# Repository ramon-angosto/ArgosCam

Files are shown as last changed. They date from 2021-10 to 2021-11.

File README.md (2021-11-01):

# ArgosCam
This project is the result of my bachelor degree final projects, for my studies in mechatronical engineering, a copy of the complete documentation of the project can be found in the documentation folder. <!-- link a carpeta -->

## Introduction

The idea of this project is the development and prototyping of a system to increase the visibility of drivers at street intersections to reduce the number of accidents that occur in these areas.

Reduced visibility increases the risk of collisions with vehicles approaching the perpendicular street to which the driver is going. Especially if the driver has to invade the road, he wants to incorporate, with his car to have visibility. This problem occurs mainly in rural areas where the streets are narrower and at the exits of the parking lots where many times the car has to cross the sidewalk to enter the street, creating a risk of running over a pedestrian.

The project develops a system to be called ARGOS CAM, referring to Greek mythology in Argos Panoptes.

ARGOS Cam consists of two main parts: one that is responsible for the collection of vehicle data (i.e. speed) and a second part that is responsible for capturing images. This second module - focused on image processing - is responsible for offering help to the driver, through image recognition, and is modulated by the first, which focuses more on aspects of vehicle electronics. The figure 1, reperesents the pipeline of the project.

<p align="center">
  pipeline
</p>

Figure 1: pipeline of the project

In Figure 2 you can see an image that represents the advantage of the system for the driver, if two cameras are placed at the front of the car.

<p align="center">
  distance_advantage
</p>

Figure 2: Distance between the driver and the front of the car

This method has some advantages in front of traditionals methods, like convex mirrors, because it's directly attached to the car and can be adjusted, also the device notifiy the user of vehicles and persons approching the car.

## Methodology
### Vehicle data collection
In order to collect the data from the car an OBD II reader will be used. This devices connects diretly to the OBD Port of the car. The speed is the only value collected from the car and will be used to turn on and off the screen, depending if the speed is below a threshold by default stablished to 2 km/h. This is done to avoid creating distractions to the driver. 

<p align="center">
  USB Obd reader
</p>

Figure 4: USB OBD II Reader

The one I have used is this [OBD Reader](https://www.amazon.es/dp/B08DG4CFH8/ref=cm_sw_em_r_mt_dp_6RFKPJA6RXC36EJ8QV0E).

### Image Capture
Any machine vision system has a first phase of image acquisition. For this task I have used two cameras **Raspberry piCameras V2** of 8 Megapixels. This are placed at the front of the car, in figure 5 you can see the point where they are placed.

<p align="center">
  camera
</p>

Figure 6: Examples of taken images

### Embedded system
The embedded system selected for this project is the [Jetson nano B01](https://www.nvidia.com/es-es/autonomous-machines/embedded-systems/jetson-nano/) from the company **Nvidia**. This board has the advantage of beeing able to acces the **CUDA** library of Nvidia and also has a **GPU**, this makes it perfect for computer vision aplications as it has a better performance than a **Raspberry Pi 4**. 

<p align="center">
  jetson nano
</p>

Figure 7: Nvidia Jetson Nano B01

The OS version I used for the project was Jetpack 4.5

The programming language used is python. A detailed explanation of the libraries used can be found in the READ_ME file inside the folder called [Code](https://github.com/ramon-angosto/ArgosCam/tree/main/code).

<p align="center">
  Jetson connections
</p>

Figure 8: Representation of component connections with the Jetson Nano. The materials used for the project are: two Raspberry Pi v2 cameras, used for image capture; a touch screen to view images and interact with the user interface; an OBD reader used for vehicle data collection; a portable battery of the Xiaomi brand, with power capacity of 5v 2.6A;for GPIO connections, four LEDs and a buzzer are used (with the necessary additional components, explained on the READ me file inside the folder called electronics) <!-- link a carpeta -->

### Background subtraction
Images acquired by front-facing cameras are processed through the Background Subtraction algorithm to isolate those objects that are moving in the scene. This is done to avoid detecting parked cars and mislabel static elements.

The algorithm used is **K-NN Background subtraction**, and can be found inside the **OpenCV library**

The selected algorithm is based on the Gaussian Mixture Model (GMM), and el K-nearest neighbor (K-NN). This is described in depth [here](https://www.sciencedirect.com/science/article/abs/pii/S0167865505003521). Generally speaking, a recursive method is presented to update the GMM parameters and update them for each pixel.

Model initialization is performed with the number of frames assigned to the NSamples variable. During this period, you define which objects belong to the background class and which objects of the moving object class by comparing the pixels in these frames. The model is then updated every N of frames, where N is the number of frames that have been defined in the History and parameter.

After the background sustraction is applied, the results goes throug a series of postprocessing steps (Backround sustraction image -> Blur -> Morphological transformations(Opening -> Closing -> Dilate) -> Contour selection).

<p align="center">
  Background sustraction 'algorithm' steps
</p>

Figure 9: Background sustraction "algorithm" steps

This allow to obtain the desired result. In this case a rectangular shaped masked arround the moving objects.

 Result examples:
 <p align="center">
  Background sustraction results
</p>

### Object detection
After the Background Subtraction, object detection is performed. Thanks to the previous step, static objects, such as parked cars, will not be recognized. This prevents the driver from being misreported, who must be alert to objects that may pose a hazard (for example, an approaching car or a pedestrian crossing the street).

To perform this task, the Mobilenet-SSD v2 network will be used pre-trained with the [COCO(Comon Object in Context)](https://cocodataset.org/#home) data set, being able to recognize up to 90 different objects and the background [35]. This network consists of two main components: MobileNet , a deep neural network with an efficient architecture designed to be used in devices with less computing capacity such as phones and embedded systems, and an SSD (Single Shot Multibox Detector) network, which allows the simultaneous detectionof multiple objects in an image.

The objects that are recognized, i.e., the permitted classes, are: vehicles (bicycles, buses, cars, motorcycles) and people. If an object is not in the classes mentioned above, it would not be detected.

When any object of the set objects is recognized, for the first time since the car stops at an intersection, a noise will sound to warn the driver. This will not sound again until some class is no longer detected while the vehicle is still stopped or once the car moves again and stops at a new intersection.

In addition to the audible warning, the device has light warnings to identify if what has been detected is a pedestrian or a vehicle and which side it is on. This will remain active as long as one of the allowed classes is detected. In the next section you can see in more detail how you will see the output that the driver will receive.

<p align="center">
  Detection representation
</p>

Figure 10: Detection representation.

## User interface and alerts
### GUI
In order to create an interface to allow the driver to interact with the device using the screen a UI has been created using PysimpleGUI. The user will be able to interact with the GUI while the car is moving at a speed of less than 2 km/h or is stopped, and will be able to decide if both cameras are used or only one. In addition to this, a button has been incorporated that allows you to disable the recognition of objects in case the driver only wants to have the cameras active and not the warnings. Below are the different screens that the user will see:

<p align="center">
  GUI screens
</p>

Figure 11: GUI screens. A) Charging screen B) Screen while the vehicle is in motion C) Screen with a single camera D) Screen with both cameras

### Luminous and sound warning
The luminous and sound warnings will activated when any of the relevant objects are recognized. There are four light signals, 2 on each side. In this way, the driver can quickly know on which side, the object has been detected. Light signals are divided into two categories: people and vehicles (cars, motorcycles, bicycles and trucks).

### 3D Design
To encapsulate the project, a housing has been designed for the screen, battery, recessed system, and electronic board, and a different one for each camera. This task was carried out using the CAD Fusion 360 program. In the folder called 3D, the following files are included: instruccions to build it and the stl. files.

<p align="center">
  ARGOS CAM
</p>

Figure 12:  ARGOS CAM system mounted on a car

## A video of the project can be found [here](https://youtu.be/hri5eU1GCwE)

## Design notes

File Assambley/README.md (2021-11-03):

# Assambley
## Materials to assamble this project
- Obd reader
- Power supply or power bank
- Jetson Nano B01 or higher version
- Sd card
- 3D printed parts
- Electronic circuit found in electronics folder
- 2 Raspberry pi cameras
- Touch Screen 
- HDMI cable
- Microusb to usb cable

## Electronics
Contains the electronics circuit and a list of components. **Go to [this folder](./Electronics/) first**

## 3d
Contains the files that have to be printed and the components to assamble the parts. **Also the instructions on how to assamble the casing.**

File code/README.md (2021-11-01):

# Necessary libraries: 
- [PySimpleGUI](https://pysimplegui.readthedocs.io/en/latest/)
- [Jetson.GPIO](https://github.com/NVIDIA/jetson-gpio)
- threading
- [obd](https://python-obd.readthedocs.io/en/latest/)
- [jetson.inference](https://github.com/dusty-nv/jetson-inference)
- [jetson.utils](https://github.com/dusty-nv/jetson-utils)
- queue

### Follow [this instruccions](https://www.pyimagesearch.com/2020/03/25/how-to-configure-your-nvidia-jetson-nano-for-computer-vision-and-deep-learning/) to intall this libraries ###
- Numpy
- OpenCv with CUDA support and contrib modules 

# Files explanation #
All the codes have comments to make them easier to understand

## synchronized_cameras_recognition_modes and video_algorithms ##
Contain the algorithms to control the cameras using threads. Also the functions to apply the background subtraction and object recognition while managing the GPIO pins.

## GPIO_ ##
This simple code can be used to test if the GPIO pins are set correctly without having to execute the complete code

## Simulation_ARGOS_CAM ##
As the name says is a simulator of how the code will perform when integrated on the car. This code dosen't require to use an OBD reader, the speed is emulated using an slider. The other parts of the code work as if they where integrated in the car.

## ARGOS_CAM ##
This code has to be executed when the board is connected to the obd reader, if not it's not going to work. It reads the values of the obd reader and with the obtained values regualte if the cameras capture images or not. The user can choose which camera is shown or if both are shown. 

## test ## 
 Contains two videos that can be tested in the **Simulation_ARGOS_CAM** algorithm.

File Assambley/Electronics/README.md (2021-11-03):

# Electronics
## Components
- Buzzer
- x4 LED
- x5 220 Ohm
- x4 Transistor P2N2222A
- x4 330 Ohms
- PCB board (70 x 48) mm
- Jumper wires

## Instructions
Solder the components following the [elecronic circuit](./electronic_circuit.jpg).
- If you want to print the case, solder all the components and the wires, except the LEDs and the buzzer, and go to the [3D folder](../3D/) for more instruccions. 
- If you don't want to print the casing you can solder all the components.

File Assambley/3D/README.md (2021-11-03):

**The base of the jetson nano case is made specifically to be used in a Mini Cooper R50, this part shoud be modifies to addapt it to other vehicles. Also the battery hole is though for a xiaomi 3 pro powerbank**

- GoPro attachment with sticker. (Used to attach cameras to the car)

# Case for the Sceen/board/pcb/powerbank
## Materials
- 3d Printer filament

### Screw (Units, type) 
- x3 (M4 x 10) (Used to attach the jetson nano case to the screen case)
- x8 (Wood screw flat M2 x 8) (Used to attach the covers to the screen case)
- x6 (M2 x 12) (Used to attach the Jetson Nanano and the pcb to the jetson nano case)
- x4 (M2 x 20) (Used to attach the screen)

### Nuts (Units, type) 
- x3 M4 
- x10 M2

### Washer
- x3 M4
- x18 M2

# Instructions
In firs place, print all the stl. files
- x6 spacers
- x2 Gopro clip
- x2 Camera case back
- **LED Cover *special instructions**
- Print all the other pieces, only one time.
- **pcb components soldered, except LEDS and BUZZER, only the correspondent cables**

## *LED Cover instructions
Preferably have a tranparent filament for the printer. This is a way to do a multimaterial print with one extruder. If you have a multimaterial printer this step will be easier.

In first place print the drawings file, using a black filament if you have some, once the print is done, don't remove it from the build plate.
Change the material, to the transparent one in case you have some, or to another color. 

With the other component (stl name: drawings), still on the build plate, start printing the cover for the LEDS (stl name: circles).

## Jeston Nano and pcb case
In first place, introduce the nuts (x6 M2), through the bottom holes of the base (stl name: Jetson_nano_base). Once this is done, the jetson nano and the pcb can be fixed to the base, using the appropiate screws x6 (M2 x 12). **Remember** to use an spacer (stl. file), between the base and the board, and also a washer between the boards and the screw.

In second place put the cover of the jetson nano case (stl name:jetson_nano_case_cover). **Before fixing it down** attach the camera cables to the jetson nano and pass it through the holes found on the top of the jetson nano case (stl name:jetson_nano_case_cover). 

Use a wood screw to hold in place the cover and the base.

## Screen case
In first place inrtoduce three M4 nuts in the appropiate hols in the interior part of the case (stl names: screen_case and screen_case1) . After this, lay the model flat on it's back, and using a tweezers introduce x4 M2 nuts, on the four holes, located at the corners of the design, and also introduce four washers in the holes located over the nuts. Also use two wood screws to hold both parts of the screen case, one hole is found under the 3 nut holes, and the other on the back part of the case.

Once this is done carefully introduce the screen and secure it using x4 (M2 x 20). **Remeber** to introduce the screen with the hdmi facing the inside. 

After the screen is fixed in place and the powerbank it's put inside the case the lid of the case (stl name: screen_case_side_cover), can be screwed down using 3 wood screws.

## Attach Jetson nano case to screen case
To join these two pieces, x3 (M4 x 10) have to be used. In the back side of the base (stl name: Jetson_nano_base), introduce three washers and using the m4 screws fix this piece to the screen case.

Then pass through the holes, at the top of the screen case, the cables for the LEDs and the buzzer, and solder the components. Use the back covers (stl name: L/R _side_cover_screen_case), to cover the cables of the screen case. Use wood screws.

Finally put the covers with the symbols for the LEDS.

# Case for the Cameras
## Materials
- 3d Printer filament
- x2 Gopro sticker attachment

### Screw (Units, type) 
- x3 (M4 x 10) (Used to attach the camera case to the gopro clip)
- x8 (M2 x 16) (Used to attach the front and the back part of the camera case)

### Nuts (Units, type) 
- x2 M4 
- x8 M2

### Washer
- x2 M4
- x8 M2

## Instructions

In firs place, print all the stl. files
- x2 Gopro clip
- x2 Camera case back
- x1 Camera case front right 
- x1 Camera case front left

### Gopro clip
Print two copies of this file, ensure it's correctly printed as it has to hold the cameras attached to the car.
Introduce a M4 washer through the bottom hole.

### Camera case
This instructions have to be followed for each camera. 
Introduce x4 M2 nuts through the holes of the back part of the case of the camera (stl name: Camera case back).
Introduce x4 M2 washer through the holes of the front part of the case of the camera (stl: Camera case front R/L )
Use the M2 screws to hold it all togheter, putting the camera in between the two parts of the case.

Introduce a M4 nut at the bottom of the front part of the case of the camera (stl: Camera case front R/L)

Using an M4 screw join the Gopro clip and the camera case

**The design is completly build. Now place it inside the car and TRY IT.**

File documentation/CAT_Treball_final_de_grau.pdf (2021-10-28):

# TREBALL FINAL DE CARRERA

### SISTEMA PER REDUIR RISC D’ACCIDENTS A CANTONADES (ARGOS[1] CAM)

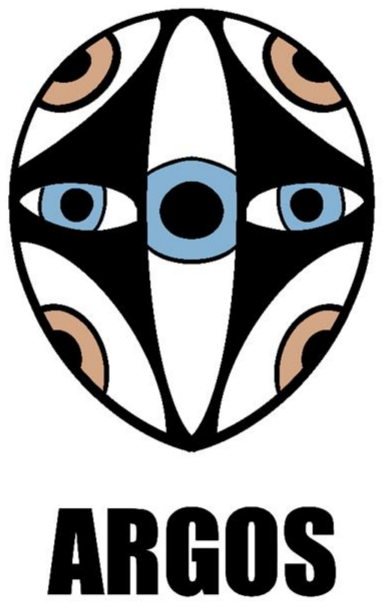
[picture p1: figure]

Nom: Ramon Angosto Artigues

Assignatura: Treball de final de grau

Grau en enginyeria mecatrònica.

Professor/a: Laura Dempere-Marco

27 octubre de 2021

Enginyeria mecatrònica

Treball de final de grau

Treball de final de grau

ÍNDEX DE CONTINGUT

Treball de final de grau

ÍNDEX D'IL·LUSTRACIONS

Il·lustració 8: Representació de les connexions dels components amb la Jetson Nano. Els materials usats per al projecte són: dues càmeres Raspberry Pi v2, usades per a la captura d’imatges; una pantalla tàctil per a la visualització d’imatges i interactuar amb la interfície d’usuari; un lector OBD usat per la recol·lecció de dades del vehicle; una bateria portàtil de la marca Xiaomi, amb capacitat per alimentar a 5v 2.6A; per a les connexions GPIO, s’usen

Il·lustració 10: A) Imatge Original B) NSamples amb valor 10 C) NSamples amb valor 3 .....26

Il·lustració 15: Etapes del Background Subtraction. a) Imatge original b) Blur c) Algoritme KNN

Il·lustració 16: Representació figurativa de capa depthwise separable (Font: Referència [37])

Il·lustració 18: Pantalles de la GUI. A) Pantalla de carrega B) Pantalla mentre el vehicle està

Treball de final de grau

Il·lustració 20: Peces de la carcassa de pantalla, bateria i plaques. A) Tapa carcassa placa
B) Base carcassa placa C ) i D) Tapes part posterior carcassa pantalla E) Carcassa pantalla
i bateria | 34
Il·lustració 21: Carcassa de la càmera dreta | 34

Il·lustració 22: Exemplificació de la GUI amb el cotxe parat, i amb el cotxe en moviment .35

Il·lustració 23: Visió de les càmeres des del punt de vista del conductor | 36

Il·lustració 24: Comparació de les mascares dels algoritmes de background Subtraction..37

Il·lustració 25: Exemples del Background Subtraction aplicat | 39
Il·lustració 26: Exemples dels avisos lluminosos en diferents situacions | 43
Il·lustració 27: Sistema Argos Cam muntat al cotxe | 44

ÍNDEX DE TAULES

Taula 1: Avaluació algoritmes de Backgroud Subtraction | 37
Taula 2: Comparació resultats algoritmes detecció d’objectes [35],[11],[22], [40] | 40

Taula 3: Velocitat de processament del reconeixement d'objectes en diferents situacions41

Taula 4: Numero de mostres per classe, i valors de TP, FP i FN | 42
Taula 5: Resultats avaluació reconeixement d'objectes | 42

Treball de final de grau

### 1. ABSTRACT

1.1 CATALÀ

En el següent Treball de Final de Grau, s’exposa el projecte dut a terme per al desenvolupament d’un dispositiu que té per objectiu augmentar la visibilitat dels vehicles a les cantonades per tal d’evitar accidents. Concretament al treball s’explicaran els mètodes que s’usen per a la identificació de possibles fonts de perill, la integració al vehicle del dispositiu i el mètode de notificació al conductor.

El projecte té dues línies metodològiques principals: 1) adquisició, processament d’imatges i reconeixement d’objectes, i 2) disseny del dispositiu electrònic. Aquestes dues línies de treball s’integren en un dispositiu funcional que un cop processades les imatges, juntament amb l’anàlisi de l’estat de moviment del vehicle, emet avisos sonors i lluminosos que indiquen la presència de vianants o vehicles que s’aproximen pels laterals.

Per dur a terme això, en primer lloc, s’han adquirit una sèrie de vídeos que han estat usats per a la realització de les proves, de forma prèvia a la integració al vehicle. Quant a la programació, aquesta s’ha dut a terme amb una Jeston Nano i el llenguatge Python junt amb una sèrie de llibreries open source, entre les quals destaca OpenCV. El disseny del dispositiu s’ha dut a terme amb el programa de disseny 3D Fusion360.

Així doncs, l’objectiu principal del projecte és augmentar la visibilitat del conductor quan es troba a una cantonada intentant girar. El dispositiu construït permet incrementar la visibilitat del conductor mitjançant l’ús de dues càmeres situades a la part del davant del cotxe i indicarà la presència d’objectes perillosos.

Els resultats obtinguts són prometedors. Per una banda, mostrar la imatge de la part frontal del cotxe ja suposa un gran avantatge de visibilitat. A més, als vídeos usats per realitzar les proves, en dies solejats o ennuvolats i les proves realitzades fora del cotxe, s’han obtingut resultats satisfactoris ja que s’avisava correctament al conductor quan un vehicle o vianant s’estava aproximant. En canvi, en condicions adverses, com pluja i boira, s’han observat alguns problemes de reconeixement dels vehicles i persones. També, a causa de la limitació de potencia al connectar la placa a una bateria portàtil per incorporar-la al cotxe aquesta no ha tingut el funcionament esperat i no ha donat els avisos correctament.

En definitiva, el projecte ha mostrat resultats que fan pensar que aquest dispositiu, amb una mica més de desenvolupament, podria ser incorporat com un sistema més d’assistència a la conducció.

Treball de final de grau

1.2 ANGLÈS

In the following Final Degree Project, the project carried out for the development of a device is exposed that aims to increase the visibility of vehicles in the corners in order to avoid accidents. Specifically, the work will explain the methods used to identify possible hazard sources, the integration into the device's vehicle and the driver notification method.

The project has two main methodological lines: 1) acquisition, image processing and object recognition, and 2) design of the electronic device. These two lines of work are integrated into a functional device that, together with the analysis of the vehicle's state of movement, emits sound and luminous warnings indicating the presence of pedestrians or vehicles approaching the sides.

To carry out this, in the first place, a series of videos have been acquired that have been used for the realization of the tests, prior to the integration into the vehicle. As for the programming, this has been carried out with a Jeston Nano and the Python language together with a series of open-source libraries, among which OpenCV stands out. The device's design was carried out with the Fusion360 3D design program.

Therefore, the main objective of the project is to increase the visibility of the driver when he is in a corner trying to turn. The built device allows to increase the visibility of the driver by using two cameras located in the front of the car and will indicate the presence of dangerous objects.

The results obtained are promising. On the one hand, showing the image of the front of the car already represents a great advantage of visibility. In addition, in the videos used to carry out the tests, on sunny or cloudy days and the tests carried out outside the car, satisfactory results have been obtained since the driver was correctly notified when a vehicle or pedestrian was approaching. On the other hand, in adverse conditions, such as rain and fog, some problems of recognition of vehicles and people have been observed. Also, due to the power limitation when connecting the hob to a portable battery to incorporate it into the car it has not had the expected operation and has not given the warnings correctly.

In short, the project has shown results that suggest that this device, with a little more development, could be incorporated as another driving assistance system.

Treball de final de grau

### 2. INTRODUCCIÓ

En aquest projecte de final de carrera es descriu el desenvolupament i prototipat d’un sistema per augmentar la visibilitat dels conductors a les cantonades per tal de reduir el nombre d’accidents que es produeixen en aquestes zones.

La visibilitat reduïda augmenta el risc de col·lisió amb vehicles que s’aproximin pel carrer perpendicular al que s’està circulant. Sobretot si el cotxe ha d’entrar a la via que es vol incorporar per tenir visibilitat. Aquest problema es dona sobretot a zones rurals on els carrers són més estrets i a les sortides dels pàrquings on molts de cops el cotxe ha de travessar l’acera per incorporar-se al carrer, havent-hi el risc d’atropellar algun vianant.

Segons la DGT el nombre d’accidents anuals en aquestes interseccions és d’aproximadament 12.000 en vies interurbanes i de 55.000 en vies urbanes, aquesta informació pertany al grup 7 de la DGT, on s’especifiquen el nombre d’accidents segons el tipus de via [2].

En el projecte es desenvolupa un sistema que serà anomenat ARGOS CAM, fent referència a la mitologia grega a Argos Panoptes [1], que era un guardià i servent d’Hera que tenia molts ulls, la qual cosa el feia molt eficient per la vigilància perquè sempre en tenia algun d’obert per vigilar. El logo del projecte fa referència a aquest mite.

ARGOS Cam consta de dues parts principals: una que s’encarrega de la recollida de dades del vehicle (i.e. velocitat) i una segona part que s’encarrega de la captació d’imatges. Aquest segon mòdul –centrat en el processat d’imatges- és l’encarregat d’oferir l’ajuda al conductor, mitjançant reconeixement d’imatge, i es troba modulat pel primer, que s’enfoca més en aspectes de l’electrònica de vehicles. L’estructura d’ARGOS Cam es presenta en la figura 1, que al seu torn recull la pròpia estructura del treball :

Treball de final de grau

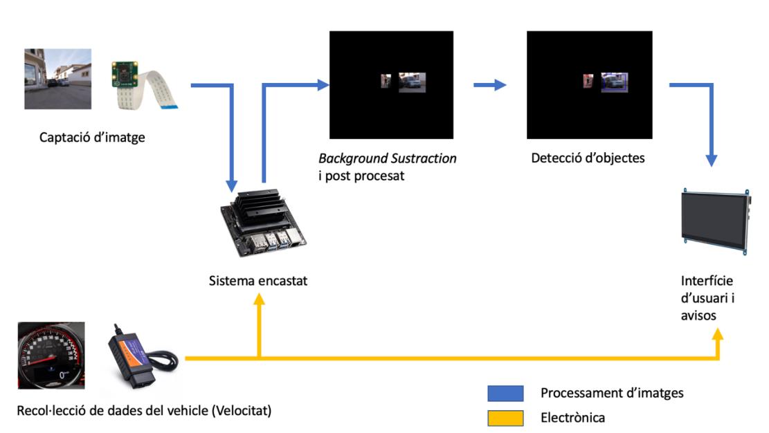
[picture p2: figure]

Il·lustració 1: Pipeline del projecte

A la següent figura 2 es pot veure una imatge que representa l’avantatge que suposa el sistema per al conductor, si es col·loquen dues càmeres a la part davantera del cotxe.

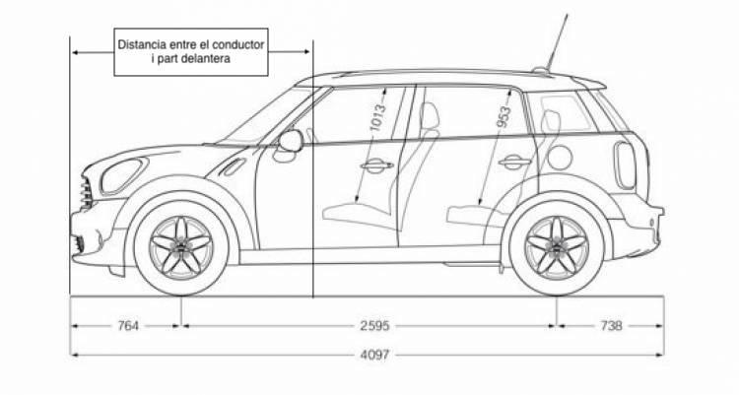
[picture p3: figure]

Il·lustració 2: Distància entre el conductor i la part davantera del cotxe

Val a dir que, a més de l’ajuda visual intrínseca que suposaran les càmeres, aquestes usaran algoritmes de processament d’imatge per poder notificar al conductor si apareix algun element al qual és necessari que presti atenció, com podria ser un cotxe que s’està aproximant o un vianant que està travessant el carrer.

Treball de final de grau

### 3. MOTIVACIÓ

La idea del projecte surt de la identificació d’un problema que he pogut veure conduint, i com ja s’ha comentat a la introducció, és la dificultat per veure si s’aproximen altres vehicles a les cantonades. És cert que en algunes cantonades hi han miralls que pretenen solucionar aquests problemes, però no hi són sempre i sovint estan en mal estat, la qual cosa en limita el seu ús.

Després d’identificar el problema he realitzat una recerca per veure el nombre d’accidents en aquestes interseccions, i l’alarmant nombre de 67.000 accidents anuals d’aquest tipus ha passat a ser l’altre motiu que m’ha motivat a dur a terme aquest projecte, per intentar reduir aquest nombre d’accidents i fer la vida de les persones més fàcil.

A més d’intentar fer la vida més senzilla a les persones, el fet de treballar amb algoritmes de Deep Learnig suposa un repte que m’estimula i em permet aplicar els coneixements adquirits al llarg dels estudis de mecatrònica i m’ofereix una oportunitat per aprofundir en coneixements que poden ser útils per un futur lloc de treball en l’entorn de la programació.

### 4. OBJECTIUS

Com s’ha comentat a la motivació d’aquest projecte, l’objectiu general és la reducció del nombre d’accidents que es produeixen a les cantonades a causa de la mala visibilitat.

Concretament es vol fer un dispositiu que es pugui integrar al cotxe, que permeti la visualització del carrer al qual el conductor es vol incorporar sense haver de treure la part davantera del cotxe i que es notifiqui al conductor si s’aproxima un altre vehicle o hi ha un vianant creuant o amb intenció de fer-ho.

Així mateix el projecte consta de dos objectius específics. En primer lloc la recol·lecció d’imatges i dades obtingudes del vehicle, junt amb algoritmes d’intel·ligència artificial per assistir al conductor en aquests tipus de vies. En segon lloc el disseny d’una interfície gràfica i un sistema d’alertes per incorporar al vehicle.

Els objectius comentats es poden ordenar per orde de prioritat de la següent forma:

1. Reduir el nombre d’accidents en aquest tipus de vies a conseqüència de la mala visibilitat

Treball de final de grau

2. Fer ús de càmeres i informació proporcionada pels sensors del cotxe, juntament amb algoritmes d’intel·ligència artificial per assistir en la conducció.
3. Dissenyar un dispositiu amb sistema d’alertes per a la incorporació al vehicle

### 5. ESTAT DE L’ART

En aquest punt es tractarà l’estat actual de la literatura que existeix sobre l’ús de dispositius per a l’assistència en conducció i cada un dels punts esmentats a la introducció que conformen el projecte.

D’entrada els sistemes d’assistència avançada al conductor, també coneguts com a ADAS [3], existeixen al sector automobilístic des del 1950, fent que la conducció sigui més segura. Alguns exemples d’aquests primers usos varen ser: sensors d’excés de velocitat i el sistema de frenada ABS. Actualment aquests sistemes es troben integrats a tots els vehicles, i la Comissió Europea planteja fer obligatòria la incorporació de més sistemes d’assistència per reduir el nombre d’accidents.

En l’actualitat han sorgit molts més d’aquests sistemes que ajuden a evitar accidents. Aquests, a més de l’assistència en carretera, també es troben relacionats amb l’ajuda al conductor dins de les ciutats. Els sistemes de frenada automàtica per proximitat, amb sensors d’ultrasons i LIDARS (Light Detection And Ranging ¹ ), i els sistemes d’ajuda a l’aparcament -amb càmeres i sensors de proximitat- són dos dels exemples més clars en aquest cas d’ús. La companyia Nissan l’any 2007 va presentar un concepte de cotxe que tenia incorporades 4 càmeres al voltant del cotxe que permetien simular una vista de dron del mateix per assistir a l’aparcament, a més de permetre seleccionar les càmeres que es veien a la pantalla [4]. També incorporava sistemes d’ultrasons per alertar d’objectes propers.

Els cotxes autònoms, principalment funcionen amb LIDARS, càmeres o la combinació d’aquestes dues tecnologies (o similars) [5]. Aquesta combinació es coneix com a sensor fusion i permet evitar alguns dels problemes que presenta cada tecnologia.

En aquest treball s’ha optat per una aproximació similar a la que va prendre Nissan i la que usen els cotxes autònoms que fan servir càmeres i sistemes d’intel·ligència artificial.

1 LIDAR: Sensor que permet determinar la distancia a un objecte o superfície mitjançant un làser polsant. [16]

Treball de final de grau

5.1 RECOL·LECCIÓ DADES DEL VEHICLE

Pel que fa a la recol·lecció de dades del vehicle, l’any 1989 es va introduir el port ODB I, als automòbils americans, que permetia controlar l’estat del motor mitjançant uns codis d’error. El 1996 es presenta el port OBD II que a més de permetre la visualització de codis d’errors permet la lectura de dades del vehicle com poden ser la velocitat, les revolucions i altres paràmetres no relacionats amb el motor. Des del 2003 aquest port és obligatori a tots els vehicles. [6, 7]

5.2 CAPTURA D’IMATGES

Un altre aspecte cabdal del sistema desenvolupat és la captura d’imatges. En aquest sentit, existeixen dos tipus principals de connexions, usats en sistemes encastats per treballs de conducció autònoma i per a la integració en sistemes encastats. Aquestes dos tipus són: MIPI CSI-2 i USB 3.0

Per un costat la connexió MIPI CSI-2 és la més usada en sistemes encastats i en telefonia mòbil. Aquesta permet una transmissió d’imatges més ràpida, 6 GB/s d’ampla de banda, i més eficient que l’USB 3.0, pel fet que no ocupa part de la CPU per funcionar. A més solen tenir una mida més reduïda tant el cos de la càmera com el cable. Per contra, presenta alguns desavantatges com són la necessitat de llibreries especials i la dificultat per usar diferents sensors a les càmeres [8].

Per l’altre costat, la connexió USB 3.0 arriba fins a un ampla de banda de 5 Gb/s i únicament s’ha de connectar per a funcionar. Com que el tipus de connexió és més comú és més fàcil trobar un dispositiu compatible o canviar un dispositiu trencat o millorar el sistema [8], [9].

A més de la connexió hi ha altres paràmetres que influeixen en la captura d’imatges, aquest són si la càmera és monocromàtica o amb un sensor a color, si està equipada amb un disparador de sensor complet o rodant, si té autoenfocament o no, si està equipada amb capacitats de visió nocturna, així com altres paràmetres que no són rellevants per aquest projecte [9].

Atès que en aquest projecte s’usarà un sistema encastat, tot tenint en compte allò que s’ha comentat en aquest apartat, s’ha optat per seleccionar una càmera amb la connexió MIPI CSI-2, sensor a color sense visió nocturna ni autoenfocament- ja que es pot produir un moviment molt ràpid davant de la càmera i l’autoenfocament podria ser més lent que el moviment que produït.

Treball de final de grau

5.3 SISTEMA ENCASTAT

Els sistemes encastats són sistemes informàtics de propòsit especial dissenyats per dur a terme una o poques tasques dedicades, i que normalment es troben limitades a la computació en temps real. Generalment s’incrusta com a part d’un dispositiu complet, sent la unitat de processament del dispositiu complet. Aquests sistemes encastats es troben a la majoria de dispositius de consum que s’usen actualmnent [10].

Avui en dia al mercat existeix una gran varietat de sistemes encastats, però a la majoria dels projectes de prototipat a cost reduït la decisió queda reduïda a dues: la Jetson Nano [11] i la Raspberry [12]. Aquestes dues plaques tenen la capacitat de fer anar un sistema operatiu i actuar com a un ordinador de petites capacitats.

Per una banda, la Raspberry va ser creada el 2012 per a ensenyar programació i com interactuar amb dispositius electrònics. Té una memòria RAM que oscil·la entre 1 GB i 8 GB, permetent l’execució de més o menys tasques paral·leles, i una CPU de 4 nuclis. Per l’altre banda, la Jetson Nano és una placa dissenyada per la companyia NVIDIA, pensada per a l’execució de programes de Machine Learning i processament d’imatge. Aquesta compta amb dues versions. Una de 2 GB de RAM i una de 4 GB, la de 4 tenint l’avantatge que compta amb dos ports MIPI CSI, per a connectar dues càmeres en paral·lel. A més a més té una GPU, aquesta aporta una gran capacitat per al computat paral·lel de tasques complexes com són el Processament d’Imatge i el Machine Learning.

A raó de què el projecte requereix dues càmeres i principalment es basa en el processament d’imatge es farà ús del sistema encastat Jetson Nano.

5.4 ALGORITMES DE VISIÓ PER COMPUTADOR PER L’ASSISTÈNCIA A LA CONDUCCIÓ EN CANTONADES

En aquest apartat es revisen els algoritmes principals de visió per computador que s’han desenvolupat per resoldre les tasques que ens ocupen en aquest projecte: Background subtraction i detecció d’objectes.

5.4.1 BACKGROUND SUBTRACTION

El Background Subtraction és una tècnica que consisteix en la separació del fons (background) d’aquells objectes que es troben en moviment en un vídeo. Una de les

Treball de final de grau

funcions en què és més usada és en la videovigilància, pel fet que permet una detecció més simplificada dels objectes que es troben en moviment. El Background Subtraction consta d’una sèrie d’etapes. Aquestes són: 1) la inicialització del fons (on en sol agafar una primera imatge), 2) la inicialització del model (que s’usarà per a la definició del que pertany al fons i el que es troba en moviment), 3) el mecanisme per actualitzar el fons, i 4) la classificació de les imatges que es van introduint [13].

Tradicionalment, els mètodes més usats per aquesta tasca són els basats en Gaussian Mixture Models (MoG) [13], ja que aquests mètodes tenen en compte canvis a la il·luminació, soroll de la imatge i objectes amb un desplaçament més lent.

A més d’aquest també existeixen altres models per a la detecció del fons que han aparegut als darrers anys. Alguns d’aquests es basen en algoritmes per segmentar el fons mitjançant xarxes neuronals i segmentació semàntica, la qual assigna cada píxel de la imatge a una classe [12, 13]. També hi ha investigadors que s’han centrat en l’ús d’altres tècniques basades en el Machine Learning com és el K-Nearest Neighbours [13].

Prèviament a la decisió final d’usar l’algoritme basat en K-Nearest Neighbour (K-NN), s’ha realitzat una comparació dels diferents algoritmes. En aquest treball, per limitacions en l’extensió no es mostra una anàlisi exhaustiva de tots els resultats obtinguts però si que es presenten en l’apartat de discussió les principals conclusions extretes d’aquest estudi.

5.4.2 DETECCIÓ D’OBJECTES

La detecció d’objectes consisteix en la combinació de dues tasques, la classificació d’un objecte que apareix a la imatge i la localització d’aquest, en altres paraules, dir en quina posició es troba un o més objectes a la imatge [16]. En l’àmbit de la visió per computador s’han desenvolupat distints mètodes per realitzar aquesta tasca, tant des de la vessant de la visió per computador clàssica com la basada en Deep Learning. Atesos que en aquest projecte ens centrarem en aquesta segona aproximació, revisem en aquesta secció els principals mètodes desenvolupats en l’àmbit de la detecció d’objectes.

Cal, però, primer fixar alguns conceptes i introduir què és el Deep Learning, així com introduir la noció de Transfer learning. El Deep Learning consisteix en l’ús d’estructures organitzades que emulen el processament d’informació que té lloc en el sistema nerviós. Aquesta estructura compta amb unitats de processament de dades, anomenades neurones connectades entre elles a través de sinapsis caracteritzades per pesos que l’algoritme aprèn a partir de les dades. El processament d’imatges és una àrea que ha estat molt beneficiada per aquestes tècniques de processament de dades. La companyia NVIDIA ha

Treball de final de grau

contribuït de forma substancial amb la creació de la llibreria CUDNN, que permet usar la GPU dels ordinadors per accelerar aquest procés [17]. Aquest mètode d’aproximació al sistema nerviós permet imitar-lo creant àrees específiques per a dur a terme tasques concretes, com pot ser l’extracció de característiques d’una imatge [18].

Per un altre costat el Transfer Learning consisteix a usar els coneixements adquirits en tasques prèvies per a entrenar una nova tasca [19]. Aquest és una forma més semblant a la manera de transmetre coneixement que tenim els humans, en comparació als mètodes tradicionals d’aprenentatge que es troben en les aproximacions clàssiques de Machine Learning. Per exemple, si a una primera tasca s’ha entrenat una xarxa neuronal per a reconèixer plantes, i més endavant es vol entrenar una xarxa diferent per a reconèixer arbres, part del coneixement de la primera xarxa es podrà reutilitzar per a la segona, sent necessària menys informació per a entrenar la segona.

Per dur a terme aquesta tasca existeixen diversos algoritmes de Deep Learning. En revisem a continuació alguns d’ells:

- Models R-CNN : el model va ser presentat al 2014 per Ross Girshick, i es basa en xarxes neuronals convolucionals. La xarxa es divideix en tres etapes: proposa una regió d’interès, s’extreuen les característiques d’aquesta i finalment es classifica [20].
- Models Fast R-CNN: es basen en el model previ i varen ser millorats pel grup de recerca de Microsoft, a diferència de l’anterior, se simplifica l’etapa de proposta de regions d’interès i combina les dues darreres etapes, permeten accelerar el procés de reconeixement [21].
- YOLO (You only look once): es tracta d’una xarxa que té com a entrada una imatge, i dóna com a resultat una bounding box i una classificació. Aquest tècnica és menys precisa que els models Fast R-CNN, però ofereix una major velocitat de processament. El funcionament d’aquest algoritme es basa en la divisió de la imatge, en quadrícules, i es proposen diferents bounding boxes, aquestes posteriorment es determinaran si pertanyen a una classe depenent de la confiança que tenen assignades [22].
- Mètodes Single Shot detector (SSD): Estan dissenyats per a la detecció d’objectes en temps real. Són capaços d’igualar la precisió de les xarxes Fast R-CNN, amb imatge de baixa qualitat. Aconsegueixen augmentar la velocitat de processat eliminant la proposta de regions i incrementen la precisió fent ús de l’extracció de

Treball de final de grau

característiques a múltiples escales. Aquest mètode es compon de dues parts un extractor de característiques basat en una xarxa neuronal i una sèrie de filtres convolucionals per a la detecció d’objectes [23], [24].

En el context d’aquest projecte, la detecció d’objectes és la part més important ja que és l’encarregada de donar l’avís al conductor de què està passant. En la secció de Metodologia s’explicarà el model que s’ha seleccionat.

Treball de final de grau

### 6. METODOLOGIA

6.1 RECOL·LECCIÓ DADES DEL VEHICLE

L’única dada que es recull del vehicle serà la velocitat. Aquesta serveix per activar i desactivar la pantalla perquè aquesta no distregui al conductor mentre està en moviment. S’ha seleccionat 2 km/h com el punt al qual s’activa la pantalla. En altres paraules, la pantalla estarà activa sempre que el vehicle es desplaci a una velocitat inferior a 2 km/h o estigui parat. El petit marge fins a zero es dóna perquè la pantalla no s’estigui activant i desactivant cada cop que el vehicle avanci uns centímetres si està parat al darrere d’un altre cotxe esperant que sigui el seu torn.

Com ja s’ha mencionat a l’estat de l’art, el mètode que s’usarà per a la recol·lecció de dades serà el port OBD II. Prèviament a la decisió d’usar el port OBD s’han plantejat altres alternatives, com són l’ús de GPS o la lectura directa del tacòmetre a través d’un cable. La primera opció ha estat descartada pel fet que existeix un retard elevat entre la lectura del GPS i la velocitat del cotxe, sobretot en velocitats baixes. El segon mètode s’ha descartat per no fer malbé el cotxe que s’usarà per fer les proves, malgrat ser el mètode més fiable.

El port OBD funciona de la següent manera: a la part inferior del volant se sol trobar el punt de connexió. Aquest recull les dades de tots els sensors de cotxe i els monitoritza constantment. Un cop es connecta el lector, que pot ser Bluetooth, per cable o amb WIFI, es transmeten les dades del vehicle al dispositiu usat per la lectura de dades. En aquest projecte s’usarà un lector amb comunicació per cable USB, com el de la imatge inferior.

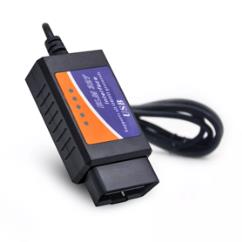
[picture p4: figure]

Il·lustració 3: Lector OBD II amb cable (Imatge obtinguda de [25])

Les dades que es transmeten del sensor es troben en forma de codi de 5 dígits. El primer dígit indica de quina part del cotxe es tracta la lectura, el segon l’organització que ha definit el codi, el tercer especifica una funció concreta del cotxe i els dos darrers són per indicar errors [7].

Treball de final de grau

Per tal de simplificar la lectura d’aquests codis s’usarà la llibreria Python-OBD [26], aquesta du incorporades funcions que permeten llegir els codis i proporcionen directament els valors d’aquests. Un cop connectat el lector, s’estableix la connexió i es declara una funció per monitoritzar el valor desitjat, en aquest cas la velocitat.

6.2 CAPTURA D’IMATGES

Qualsevol sistema de visió per computador té una primera fase d’adquisició de la imatge . Per aquesta tasca s’usaran dues càmeres Raspberry piCameras V2 de 8 Megapixels. Aquestes van col·locades a la part frontal del cotxe, a la imatge 5 es pot veure el punt on van col·locades.

Il·lustració 4: Raspberry piCamera V2 (Imatge obtinguda de [27])

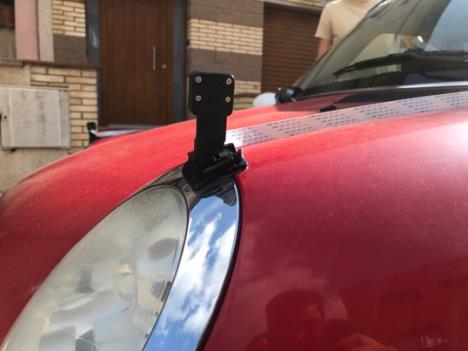
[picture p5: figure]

Il·lustració 5: Posició de la càmera al cotxe

Per obtenir les imatges de les càmeres es farà ús de la llibreria OpenCV, de la que es donaran més detalls més endavant, i el framework multimèdia GStreamer que permet ajustar el format de sortida de la imatge, ajustar les dimensions de la imatge capturada i la freqüència de captura (framerate).

Treball de final de grau

El framerate és un paràmetre molt important en aquest projecte ja que el sistema ha de ser capaç de captar els cotxes en moviment. En principi el límit de velocitat urbà és de 30 km/h, però com a marge de seguretat es posarà que s’ha de detectar fins a 60 km/h (17.7 ms/s) en cas que algun vehicle vagi a una velocitat superior a la permesa.

Aquesta velocitat permet determinar el mínim framerate necessari per poder captar cotxes a 60 km/h. D’aquesta manera, si es prenen 18 imatges per segon, el cotxe s’hauria desplaçat aproximadament 1 metre entre cada imatge. A mesura que s’augmenta el framerate la distància que es desplaça el cotxe per cada frame es redueix. En el nostre cas s’estableix el framerate a 60 FPS², per tal de permetre un desplaçament màxim del cotxe entre captures de 30 cm.

Per tant, la càmera queda ajustada amb els següents paràmetres:

Mida del marc de captura: 1280 x 720 píxels

Framerate: 60 FPS

Val anticipar que els 60 FPS no s’acabaran donant ja que els algoritmes que s’expliquen més endavant faran que el procés de captura vagi més lent.

A la il·lustració 6 es mostra una representació de la posició des de la que es capturen les imatges pel projecte. Tal i com es pot apreciar, el conductor no envaeix la via.

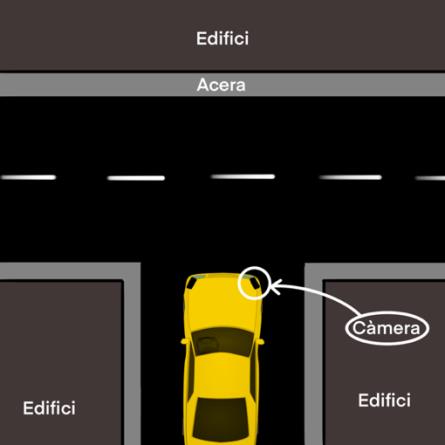
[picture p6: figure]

Il·lustració 6: Posició del cotxe per la captura d 'imatges

2 FPS: Frames per segon

Treball de final de grau

A continuació, es presenten una sèrie d’imatges preses des de la posició indicada, i a l’annex 1, es poden trobar més exemples.

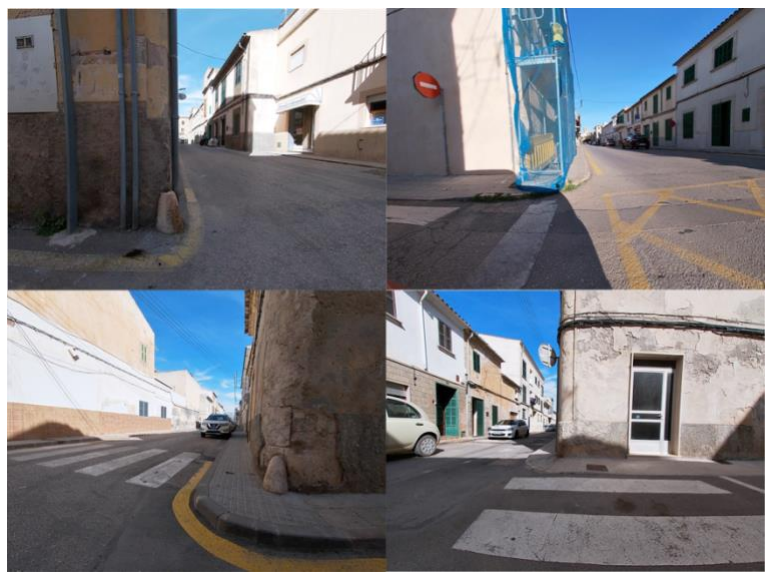
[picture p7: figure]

Il·lustració 7: Exemples de captures d'imatges a diferents cantonades

6.2.1 ÈTICA O PROTECCIÓ DRETS D’IMATGE

Atès que en aquest projecte es capturen imatges, és necessari clarificar que cap de les imatges que usa el dispositiu pel processat és emmagatzemada, d’aquesta manera es manté la privacitat de les persones que puguin aparèixer en el moment que les càmeres estan funcionant.

L’únic moment en el qual s’han emmagatzemat imatges ha estat en el moment en què es preparava un conjunt de dades de mostra per poder realitzar les proves, i en aquests, únicament apareixen persones que han donat el seu consentiment per aparèixer als vídeos.

Treball de final de grau

6.3 SISTEMA ENCASTAT

Tal i com s’ha indicat anteriorment, el sistema encastat que s’usarà en el projecte és una Jetson Nano B01 de la marca Nvidia. Aquesta placa és el lloc on es donarà tot el processament de les dades. El sistema operatiu que té instal·lat és el Jetpack 4.5, que està basat en Linux 18.0. El llenguatge de programació que s’usarà per dur a terme el processament de les dades i els avisos al conductor serà Python 3.7.

El programa que controla el projecte fa ús de les següents llibreries:

- Python-OBD: Com s’ha comentat a l’apartat de la lectura de dades del vehicle aquesta llibreria, permet la comunicació amb el lector OBD, i permet obtenir la velocitat del cotxe per poder usar-la i regular si la pantalla està encesa o no.
- OpenCV (amb CUDA): És la llibreria que s’encarrega de tot el processament d’imatge i de la captura del vídeo. És dins d’aquesta que es troben els algoritmes de Background Subtraction que s’expliquen al següent apartat. A més, aquesta llibreria juntament amb la llibreria Tensorflow és l’encarregada de la detecció d’objectes. Com que el sistema encastat compta amb una GPU que pertany a Nvidia es pot beneficiar de la llibreria CUDA, que ofereix un processament d’imatge accelerat.
- Tensorflow: es una llibreria de codi obert desenvolupada per Google, que s’usa per a l’entrenament i execució d’algoritmes de Deep Learning.
- Jetson inference: la funció d’aquesta llibreria és l’optimització de xarxes neuronals per tal que es puguin fer servir a la Jetson Nano.
- PySimpleGUI: aquesta llibreria és usada per crear la interfície d'usuari perquè aquest interactuï amb la pantalla i pugui veure les càmeres.
- Jetson.GPIO: permet controlar els pins GPIO de la Jetson, permetent activar els LEDs i avisos sonors que s’usaran per notificar a l’usuari de la presència d’algun objecte reconegut.

El codi escrit per al projecte es troba inclòs als annexos, aquest està format per dos scripts. El primer, inclou una classe que s’ha creat per gestionar els algoritmes de processament d’imatges. Inclou els algoritmes de background Subtraction i de reconeixement d’imatge. El segon script, serveix per englobar tot el codi, i permet la lectura del OBD.També gestiona la GUI i es comunica amb el primer script per obtenir els resultats dels processament d’imatge.

En la següent figura es mostra l’esquema de connexions, per entendre com es comunica cada element amb la Jeston Nano.

Treball de final de grau

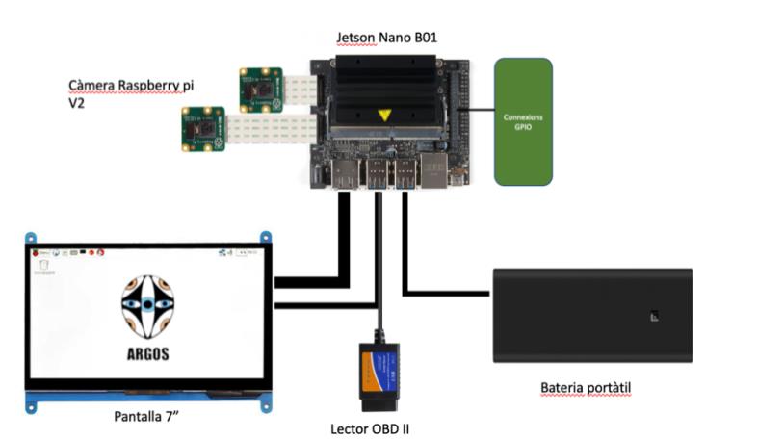
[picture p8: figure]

Il·lustració 8: Representació de les connexions dels components amb la Jetson Nano. Els materials usats per al projecte són: dues càmeres Raspberry Pi v2, usades per a la captura d’imatges; una pantalla tàctil per a la visualització d’imatges i interactuar amb la interfície d’usuari; un lector OBD usat per la recol·lecció de dades del vehicle; una bateria portàtil de la marca Xiaomi, amb capacitat per alimentar a 5v 2.6A; per a les connexions GPIO, s’usen quatre LEDS i un buzzer (amb els components addicionals necessaris)

Com es pot veure a la Figura 8, la placa és alimentada a través d’una bateria portàtil. Aquesta no és l’opció més recomanable i seria millor alimentar la placa directament amb la bateria del cotxe i un convertidor reductor de 12 V a 5V però a causa d’un problema amb la bateria del cotxe usat per les proves s’ha optat per aquesta solució.

6.4 BACKGROUND SUBTRACTION

Les imatges adquirides per les càmeres frontals són processades a través de l’algoritme de Background Subtraction per tal d’aïllar aquells objectes que es troben en moviment en l’escena. A continuació s’expliquen els criteris emprats per seleccionar l’algoritme amb què es treballarà i es detalla com funciona aquest.

6.4.1 SELECCIÓ DE L’ALGORITME

Per tal de seleccionar l’algoritme més adequat per aquest projecte s’han avaluat diferents opcions de Background Subtraction. En particular, s’han considerat els

Treball de final de grau

algoritmes: k-NN, MOG, MOG2 i GMG³. Per fer-ho s’han aplicat aquests algoritmes sobre una sèrie de vídeos, i s’han guardat les màscares resultants. Aquestes han estat comparades enfront del resultat esperat.

Aquests resultats esperats s’han obtingut fent un etiquetat de forma manual amb l’eina de disseny gràfic Photoshop. Amb aquesta s’ha creat una màscara representativa del ground truth, seguint la forma d’etiquetar usada per l’algoritme, dit d’un altre manera, s’ha fet un bounding box, al voltant de l’objecte que es troba en moviment tal com l’hauria de fer l’algoritme. El color negre pel fons, amb etiqueta 0, i el color blanc per l’element mòbil, amb etiqueta 1.

L’algoritme usat per aquesta valoració s’ha obtingut a partir de les següents referències [28], [29]. El rendiment de cadascú dels algoritmes ha estat avaluat mitjançant una matriu de confusió, que representa les quatre possibles combinacions entre els valors reals i els obtinguts a partir de la màscara binària generada per l’algoritme.

En el nostre cas, la classe fons, pertany al valor negatiu, és a dir, 0 i la classe en primer pla o objecte en moviment, seria el valor positiu, és a dir, 1.

La matriu de confusió es defineix a partir dels següents resultats de la classificació:

MATRIU DE CONFUSIÓ:

Positiu vertader (PV): Representa el nombre de prediccions positives, és a dir, nombre de píxels que han estat etiquetats amb la classe 1 i que realment pertanyen a aquesta classe.

Negatiu vertader (NV): Representa el nombre de prediccions negatives, és a dir, nombre de píxels que han estat etiquetats amb la classe 0 i que realment pertanyen a aquesta classe.

Fals positiu (FP): Representa el nombre de mostres que s’han classificat com a positives (primer pla) però en realitat són de negatives (fons).

3 GMG: Algoritme està basat en l’article [42]. La base del seu funcionament es l’estimació d’imatge i l’aplicació per píxel de filtres Bayesians

Treball de final de grau

Fals negatiu (FN): Representa el nombre de mostres que s’han classificat com a negatives (fons) però en realitat són de positives (primer pla).

MESURES DE RENDIMENT DE L’ALGORITME:

A partir d’aquest s’obtenen les següents mesures:

Precisió: És la ràtio de píxels classificats correctament en comparació a tots els píxels avaluats. Aquesta mesura és molt sensible per avaluar conjunts de dades en què les classes no estiguin balancejades. A l’equació 1 es pot veure com es calcula.

Precisió =

PV+NV
PV+NV+FP+FN

(Eq. 1)

Sensitivitat o rati de positius vertaders: Correspon a la proporció de mostres classificades com a positius vertaders (PV), respecte a tots els positius (PV + FP ). A l’equació 2 es troba definit com fer aquesta mesura. Aquesta mesura pot ser interpretada en com de bé l’algoritme detecta els objectes que es troben en moviment.

Sensitivitat =

PV
PV+FP

(Eq. 2)

Especificitat o rati de fals positiu: En canvi l’especificat és la proporció de mostres negatives classificades com a positives (FP) respecte a totes les que realment són negatives (NV + FP) com es mostra a l’equació 3. Aquest valor s’interpreta com la capacitat de detectar correctament el que és fons de les imatges obtingudes.

Especificitat =

FP
NV+FP

(Eq. 3)

Valor F1: Es tracta d’una mesura que relaciona els valors de precisió i la sensitivitat. Aquesta mesura és bastant útil quan es té una gran desigualtat a les dades usades per a l’avaluació, i aquest és un dels casos en què és necessari usar-la, pel fet que la majoria dels píxels a les imatges pertanyen al fons. A l’equació següent es presenta com es faria el càlcul.

F1 = 2 ∗

(Sensitivitat∗Precisió)
(Sensitivitat+Precisió)

(Eq. 4)

Treball de final de grau

A l’apartat de resultats es presentaran els resultats obtinguts en aquest estudi. En la discussió s’analitzen aquests resultats i les seves implicacions.

6.4.2 KNN BACKGROUND SUBTRACTION

L’algoritme seleccionat es basa en el Gaussian Mixture Model (GMM), i es tracta del K-nearest neighbour (K-NN). Aquest es descriu en profunditat en [30]. A grans trets, es presenta un mètode recursiu per anar actualitzant els paràmetres del GMM, i actualitzar-los per a cada píxel. L’algoritme K-NN es troba inclòs a la llibreria OpenCv [31] i compta amb una sèrie de paràmetres que s’han d’ajustar per arribar al funcionament desitjat de l’algoritme. La inicialització del model es du a terme amb el nombre de frames assignats a la variable NSamples.Durant aquest període es defineix quins objectes pertanyen a la classe fons i quins a la classe d’objecte en moviment mitjançant la comparació dels píxels d’aquests frames. Llavors el model es va actualitzant cada N de frames, on N és el número frames que s’hagin definint al parametre History.

El K-NN és un algoritme principalment usat per problemes de classificació predictiva. Aquest algoritme no té una fase d’entrenament específica sinó que durant el mateix entrenament es du a terme una tasca de classificació. És un algoritme no paramètric, és a dir, que l’entrenament es du a terme sense informació de les dades entrades [32]. El principi de funcionament de l’algoritme es basa en un sistema de votació dut a terme entre els K veïns més propers i en la similitud de característiques -respecte a les dades d’entrenament- per predir la classificació de les noves dades. La següent imatge presenta un exemple senzill del funcionament de l’algoritme. El punt negre és la nova dada que s’està avaluant. Si K=3, hem de mirar els tres punts que estan més a prop. Com que la majoria d’aquests són vermells, el punt nou s’assigna a la classe vermella.

Il·lustració 9: Exemple K-NN obtingut de [32].

Els paràmetres necessaris per ajustar el funcionament de l’algoritme són:

Treball de final de grau

History: Es tracta del número de frames que afectarà la modificació dels pessos assignats a la classe fons i objecte que està en moviment . Mitjançant aquest paràmetre es pot ajustar la referència sobre la qual es compararà el nou frame per comprovar si aquest ha canviat o no. Aquest valor s’ha establert a un valor de 100. Si el valor és massa petit els canvis en la imatge triguen massa temps a aparèixer reflectits, i si el valor és massa elevat, la màscara canvia en massa freqüència provocant que el mínim canvi en la il·luminació modifiqui la màscara de manera dràstica. El framerate de la càmera afectarà al valor d’aquest paràmetre, ja que, com major sigui aquest menys temps es trigarà a actualitzar.

Nsamples: Defineix el nombre de mostres guardades en memòria amb les quals compta l’algoritme de Background Subtraction per comparar i assignar una nova classe als píxels del nou frame. Si es compta amb un número de mostres molt reduïdes, la segmentació del fons té molt de soroll com es pot observar a la imatge inferior. En canvi amb el valor ajustat s’aconsegueix una màscara més uniforme. Per aquest projecte s’usa un valor de 10.

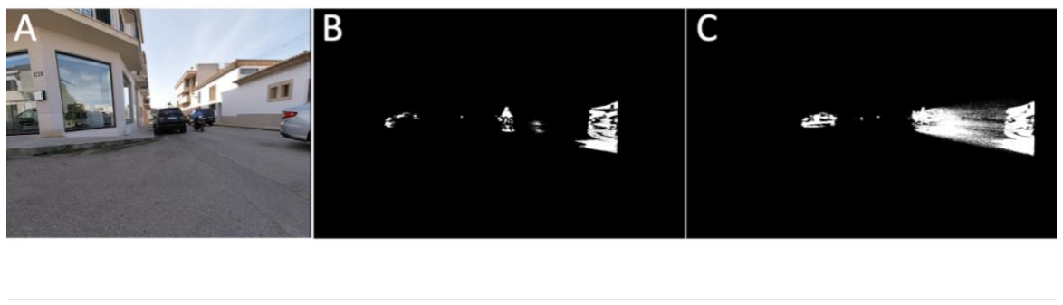
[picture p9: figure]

Il·lustració 10: A) Imatge Original B) NSamples amb valor 10 C) NSamples amb valor 3

KNNSamples: El paràmetre K-NN Samples, és la variable K que es troba sempre definida als algoritmes de K-NN. Amb aquest s’ajusta el nombre de mostres amb les que es compararà cada píxel per decidir si pertany a una classe o a l’altre, la que tingui més vots serà l’assignada. A l’article original d’aquest algoritme, es recomana usar un valor que es trobi entre 3 i 60. [30] A mesura que s’augmenta el valor de K la precisió amb la qual es detecta el fons també augmenta perquè el píxel actual es compara amb un major nombre de píxels propers per a ser classificat com a fons o com a objecte en moviment, però com a efecte negatiu d’aquest augment trobem que es redueix la velocitat a la qual s’obté la màscara. En aquest cas s’usarà un valor de 3, ja que un valor superior provoca que l’algoritme funcioni massa lent.

Treball de final de grau

Detect shadows: Modificant el valor d’aquesta variable es pot seleccionar si es consideraran les ombres com a fons o com a objectes en moviment, depenent de si la variable està activa o no, aquesta es pot ajustar per descartar només ombres molt marcades o totes les que apareguin al frame. Per aquest projecte es detectaran tots els tipus d’ombra pel fet que qualsevol petit canvi en la imatge pot sevir per obtenir un reconeixement més ràpid de l’objecte.

Un cop aplicat l’algoritme de Background Subtraction es realitzaran un seguit d’operacions morfològiques sobre la imatge binària obtinguda per tal de facilitar la detecció d’objectes.

6.4.3 TRANSFORMACIONS MORFOLÒGIQUES

Les transformacions morfològiques són operacions basades en l’estructura geomètrica dels objectes de la imatge. Aquestes tenen com entrada una imatge, normalment binària, i un element estructural o kernel. Fent ús de la combinació d’aquests dos i de l’operació desitjada, la màscara es veu modificada [33]. En aquest treball es fa ús de dos kernels diferents, permetent aplicar-los en casos diferents. El primer té forma de creu i una mida de 5x5 píxels i el segon té forma d’el·lipse, amb una mida de 7x7 píxels. La forma el·líptica engloba més superfície, la qual cosa permet que la màscara s’ampliï de manera més significativa.

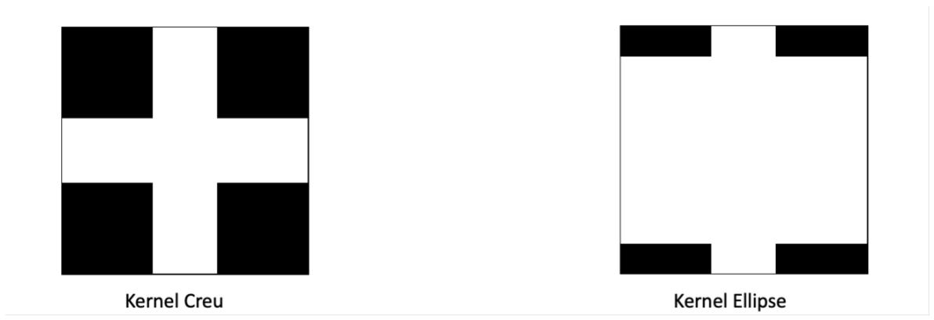
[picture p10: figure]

Il·lustració 11: Matrius que conformen els kernels

Les transformacions morfològiques usades es duen a terme en el següent ordre:

OPENING:

Treball de final de grau

En primer lloc és durà a terme un Opening, aquesta operació és la combinació de dues operacions, una erosió seguida d’una dilatació de la màscara. Freqüentment és usada per eliminar soroll a les màscares, per això s’ha usat en primer lloc. D’aquesta manera s’eliminen petits elements que poden haver estat detectats erròniament. Aquesta operació serà l’única que usarà el kernel amb forma de creu per tal d’evitar que la resta de la màscara es vegi massa modificada.

Il·lustració 12: Exemple de l'efecte de Opening (Font: Referència [33])

CLOSING

Es tracta de l’operació contrària a l’Opening. En aquest cas la seva funció és tancar les petites obertures que poden quedar a la màscara.

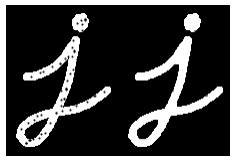
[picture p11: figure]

Il·lustració 13: Exemple de la funció Closing (Font: Referència [33])

DILATE

Finalment fent ús de la funció Dilate s’expandirà la màscara per tal de reduir la possibilitat que alguna part de l’objecte en moviment quedi emmascarat.

Il·lustració 14: Exemple de la funció Dilate (Font: Referència [33])

Treball de final de grau

6.4.4 SELECCIÓ DE CONTORNS I BOUNDING BOX

Per acabar el Background Subtraction, se cercaran els contorns de la màscara obtinguda després de la transformació morfològica atès que pot ser que al processat anterior podrien quedar obertures a la màscara, la qual cosa Els contorns que s’obtinguin seran usats per a generar unes bounding boxes -que encapsularan aquells contorns que hagin passat un filtre de mida- aconseguint l’objectiu d’ampliar les màscares dels objectes que estan en moviment.

La següent il·lustració presenta els diferents passos que va seguint l’algoritme per aïllar els elements mòbils de les imatges. La imatge A, és l’original. Després aquesta es suavitza (per tal d’eliminar soroll), i se li aplica l’algoritme de background Subtraction. A la imatge D es pot veure com els petits puntets que hi ha al cotxe de la imatge C desapareixen quan s’ha aplicat l’opennig. A les imatges E i F es veu l’efecte d’aplicar el closing i el dilate. Finalment es veu que l’algoritme de selecció de contorns i bounding box, crea un rectangle al voltant de l’objecte mòbil.

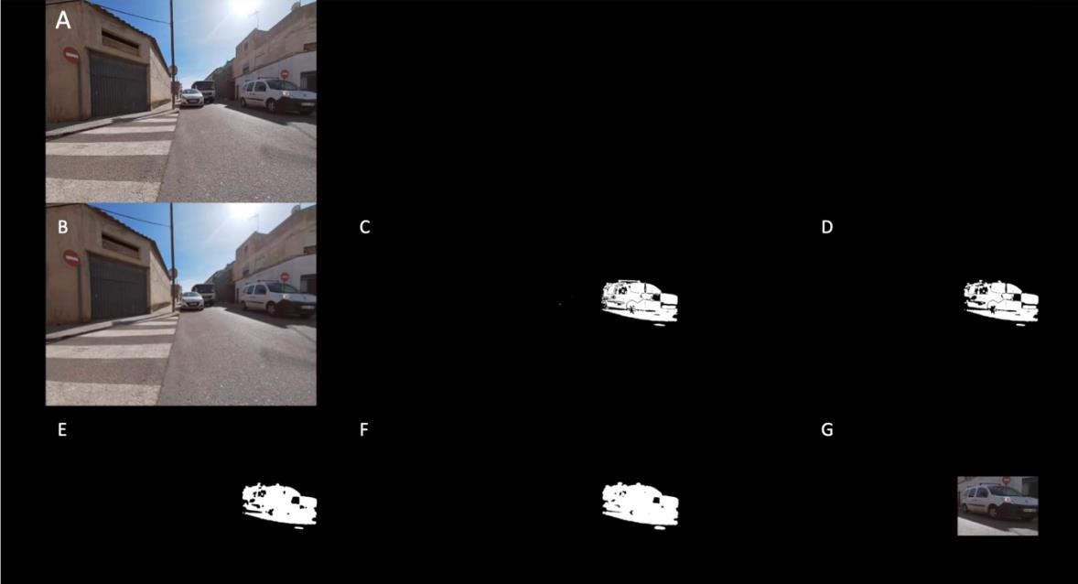
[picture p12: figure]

Il·lustració 15: Etapes del Background Subtraction. a) Imatge original b) Blur c) Algoritme KNN d) Opening E) Closing F) Dilate G) Find Contours & Bounding Box

Treball de final de grau

6.5 DETECCIÓ D’OBJECTES

A continuació del Background Subtraction es realitza la detecció d’objectes. Gràcies al pas anterior els objectes estàtics, com són els cotxes aparcats, no es reconeixeran. D’aquesta manera s’evita que es notifiqui erròniament al conductor, qui ha d’estar alerta d’aquells objecte que poden suposar un perill(e.g. un cotxe aproximant-se o un vianant travessant el carrer).

Per fer aquesta tasca s’usarà la xarxa Mobilenet-SSD v2 preentrenada amb el data set COCO(Comon Object in Context) [34], sent capaç de reconèixer fins a 90 objectes diferents i el fons [35]. Aquesta està composta per dos components principals: MobileNet [36], una xarxa neuronal profunda amb una arquitectura eficient pensada per poder ser usada en dispositius amb menor capacitat de computació com poden ser telèfons i sistemes encastats, i una xarxa SSD (Single Shot Multibox Detector) [23], que permet la detecció de simultània de múltiples objectes en una imatge.

MOBILENET

Es tracta d’una xarxa neuronal convolucional que funciona com a classificador. La característica que la diferencia de la resta -i permet que aquesta pugui treballar de manera més eficient en sistemes de menor prestacions- és l’ús d’un nou tipus de capes convolucionals anomenades Depthwise Separable Convolutions. Aquestes estan basades en una capa convolucional normal, de la dimensió desitjada, però en aquest cas s’afegeixen dues capes convolucionals 1x1, una al davant i l’altre al darrere. La primera té la funció d’expandir els tensors i la darrera que actua com un coll d’ampolla reduint el nombre de tensors. Dit d’una altra manera, és com si es descomprimissin les dades recollides a la imatge i un cop processades es comprimís el resultat [32,33].

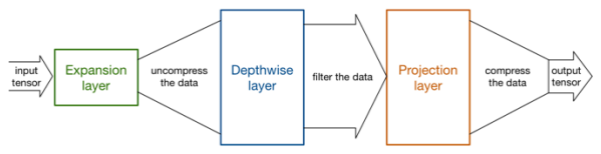
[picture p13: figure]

Il·lustració 16: Representació figurativa de capa depthwise separable (Font: Referència [37])

SSD

Realitza la classificació i la localització en una sola passada de la xarxa, i simultàniament prediu la classe i les bounding box a mesura que processa la imatge.

Treball de final de grau

A la imatge 17 es mostra l’arquitectura que té. En aquesta es pot apreciar que Mobilenet queda integrat a la primera part i funciona com a extractor de característiques per a SSD. Això és possible gràcies a la flexibilitat del SSD que permet canviar l’arquitectura bàsica que usa [37].

Aquesta xarxa produeix un nombre fix de bounding boxes i una puntuació per la presència d’instàncies d’objectes d’una classe dins aquestes bounding boxes. Finalment acaba amb un pas de Non-maximum supression per agrupar les bounding boxes amb un alt grau de solapament. [23]

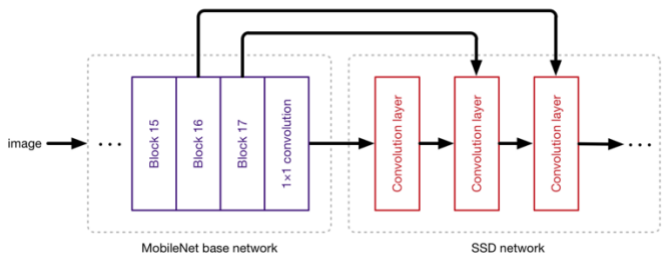
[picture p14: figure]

Il·lustració 17: Estructura de la xarxa MobileNetSSD-v2 (Font: Referència [37])

Un cop definit l’algoritme de reconeixement d’objectes que s’utilitza, expliquem ara de quina manera es tracten les dades que s’obtenen d’aquest. Els objectes que es reconeixen, i.e. les classes permeses, són: vehicles (bicis, busos, cotxes, motos) i persones. En cas que un objecte no estigui a les classes mencionades, aquest no es detectaria. Per exemple, en el cas que una pilota rodés al mig del carrer no es detectaria, però si un nin la seguís per agafar-la aquest sí que seria detectat, ja que, la classe persona sí que es detecta. Més endavant, a l’apartat de discussió, es comentarà què passaria en cas que aparegués un objecte que no està a la llista de reconeguts.

Quan es reconegui algun objecte dels objectes establerts, per primer cop d’ençà que el cotxe es para a una cantonada, sonarà un soroll per avisar al conductor. Aquest no tornarà a sonar fins que no es deixi de detectar alguna classe mentre que el vehicle segueixi parat o un cop que el cotxe es torni a moure i es pari a una nova cantonada.

A més de l’avís sonor el dispositiu compta amb uns avisos lluminosos per identificar si el que s’ha detectat és un vianant o un vehicle i a quin costat d’aquest es troba. Aquests es mantindran actius en tot moment que es detecti una de les classes vàlides. A l’apartat següent es podrà veure amb més detall com es veurà la sortida que rebrà el conductor.

Treball de final de grau

6.6 INTERFÍCIE D’USUARI I AVISOS

Com s’ha comentat anteriorment, per la creació de la interfície d’usuari es fa servir PySimpleGUI. L’usuari podrà interactuar amb la GUI mentre que el cotxe es desplaci a una velocitat inferior a 2 km/h o estigui parat, i podrà decidir quina de les càmeres es veu. A més d’això s’ha incorporat un boto que permet desactivar el reconeixement d’objectes, en cas que el conductor únicament desitgi tenir actives les càmeres i no els avisos. A continuació es presenten les diferents pantalles que veurà l’usuari:

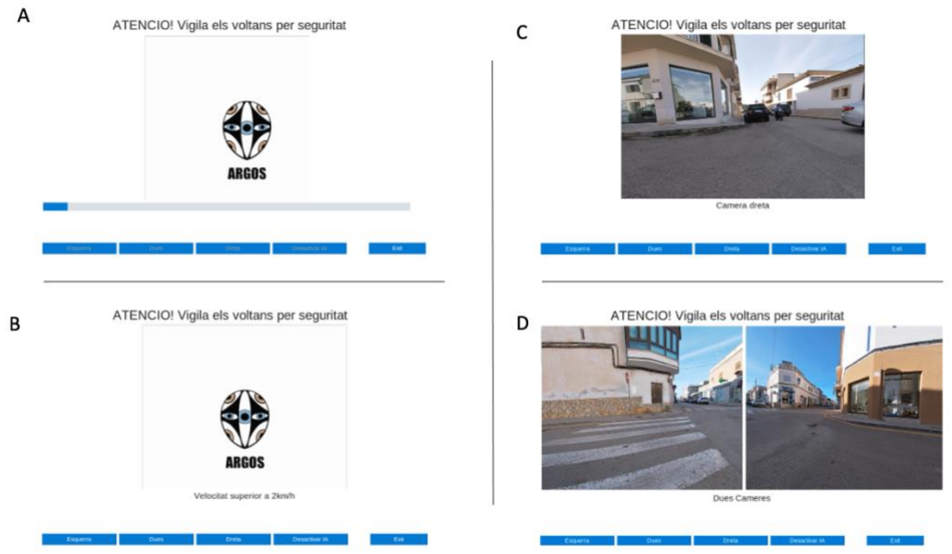
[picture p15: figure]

Il·lustració 18: Pantalles de la GUI. A) Pantalla de carrega B) Pantalla mentre el vehicle està en moviment C) Pantalla amb una sola càmera D) Pantalla amb les dues càmeres

Els avisos lluminosos i sonors estan integrats en el circuit electrònic que es mostra en la Figura
19. Aquests s’activaran quan es reconegui algun dels objectes rellevants a les càmeres. Hi ha quatre senyals lluminosos, 2 a cada banda. D’aquesta manera el conductor pot saber ràpidament en quin costat s’ha detectat l’objecte/s. Els senyals lluminosos es divideixen en dues categories: persones i vehicles (cotxes, motocicletes, bicicletes i camions).

Treball de final de grau

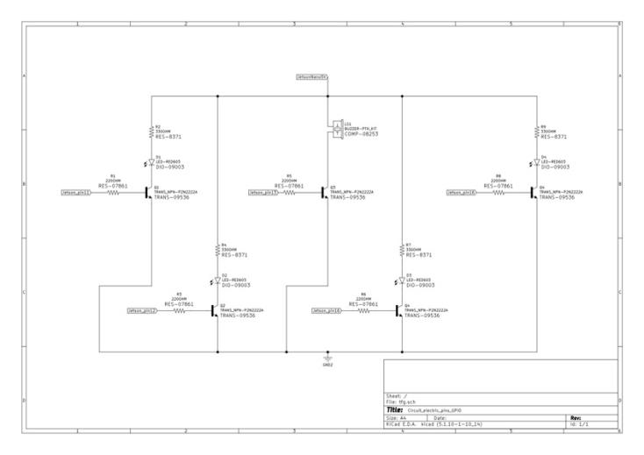
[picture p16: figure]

Il·lustració 19: Circuit electrònic generat amb KiCad

Per encapsular el projecte, s’ha dissenyat una carcassa per la pantalla, la bateria, el sistema encastat i la placa d’electrònica, i una altra diferent per cada càmera. Aquesta carcassa també inclou el mètode de subjecció al cotxe. Aquesta tasca s’ha dut a terme fent ús del programa de CAD Fusion360. També s’han generat els plànols de disseny de les diferents parts.

A les imatges 20 i 21, es mostren les diferents parts del disseny final. A l’annex 4 es poden trobar els plànols de disseny de cada peça.

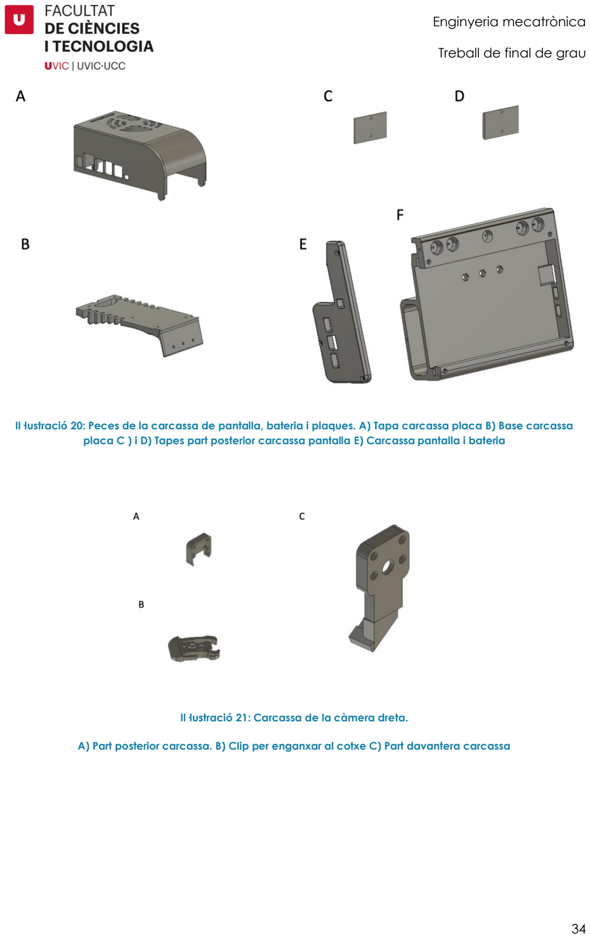
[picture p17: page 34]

Treball de final de grau

Il·lustració 20: Peces de la carcassa de pantalla, bateria i plaques. A) Tapa carcassa placa B) Base carcassa placa C ) i D) Tapes part posterior carcassa pantalla E) Carcassa pantalla i bateria

Il·lustració 21: Carcassa de la càmera dreta.

A) Part posterior carcassa. B) Clip per enganxar al cotxe C) Part davantera carcassa

Treball de final de grau

### 7. RESULTATS

A fi de poder avaluar els resultats que impliquin processament d’imatge, s’han gravat 12 vídeos a diferents cantonades, amb les càmeres col·locades a la seva posició, per tal de crear un conjunt de dades per la validació dels algoritmes proposats. D’aquests, s’han seleccionat 5 vídeos de forma aleatòria dels quals s’han recollit 4000 imatges (frames). De les 4000 imatges, se n’han tornat a seleccionar 300 de manera aleatòria.

7.1 RECOL·LECCIÓ DADES DEL VEHICLE

La recol·lecció de les dades es du a terme de forma força precisa. Això es deu al fet que el senyal que s’envia al tacòmetre és el mateix que llegeix el lector OBD. A la imatge 22, es pot veure com queda la pantalla quan el cotxe va a una velocitat superior a 2 km/h.

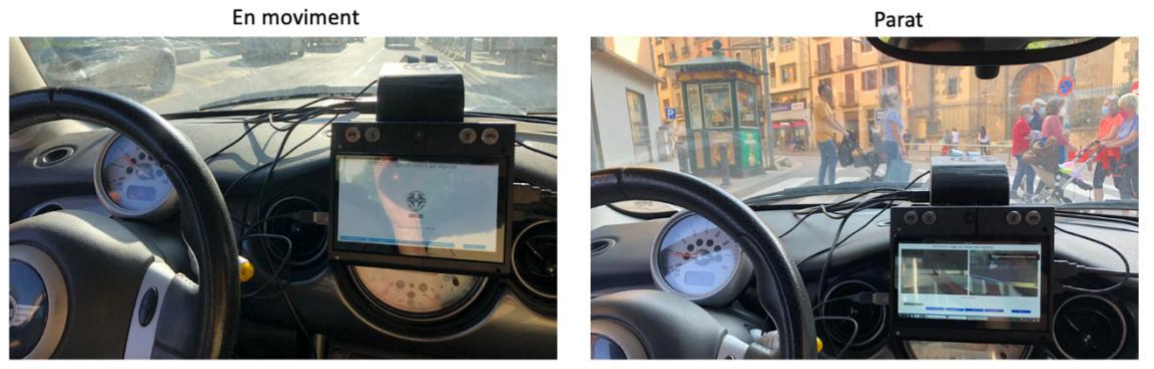
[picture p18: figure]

Il·lustració 22: Exemplificació de la GUI amb el cotxe parat, i amb el cotxe en moviment

La connexió entre la placa no ha pogut ser establerta a causa d’un error de la placa adquirida per el projecte. Però per provar el funcionament del lector s’ha fet ús d’un ordinador amb aquest s’ha provat que el funcionament d’aquest era adequat i es complia la funció de recol·lectar la velocitat del cotxe i activar i desactivar la pantalla.

Cal comentar que existeix un petit retard, de 4 segons, a causa de la comunicació sèrie entre la l’ordinador i el lector. Aquest no té una importància cabdal i realment no afecta de forma significativa el resultat final del projecte. La principal conseqüència és que la GUI tarda aquest temps de més a canviar.

7.2 MILLORA DE LA VISIBILITAT

Treball de final de grau

Un cop revisades les diferents imatges del data set i els vídeos es pot afirmar que el posicionament de les càmeres permet aconseguir l’objectiu proposat de reduir la distància que el cotxe envaeix el carrer, millorant així la visibilitat del conductor i reduint el risc d’accident.

A la següent imatge, es pot veure un exemple des del punt de vista del conductor de com es veuria la imatge al dispositiu.

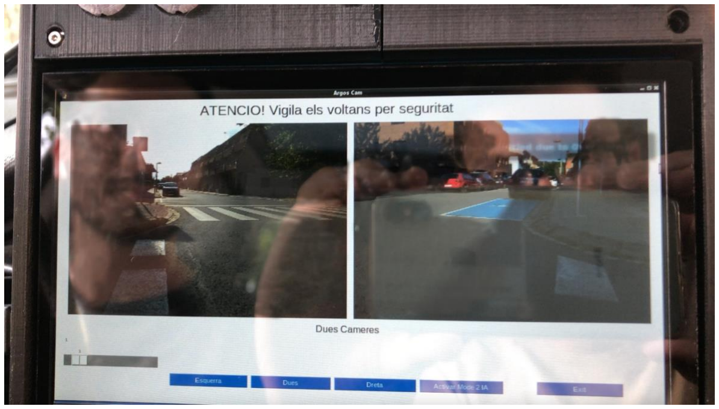
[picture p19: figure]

Il·lustració 23: Visió de les càmeres des del punt de vista del conductor

7.3 BACKGROUND SUBTRACTION

En aquest apartat es presentaran els resultats de la selecció de l’algoritme de fons i alguns exemples de les imatges obtingudes després de que s’hagi aplicat el Background Subtraction.

Amb l’objectiu de seleccionar i avaluar l’algoritme de Background subtraction, s’ha fet ús del conjunt d’imatges mencionat al principi de l’apartat . Per poder comparar els resultats obtinguts amb els esperats, s’ha obtingut el ground-truth fent ús de Photoshop, tal com s’ha indicat a l’apartat de metodologia. La següent il·lustració presenta un exemple de les mascares obtingudes comparades amb el ground-truth.

Treball de final de grau

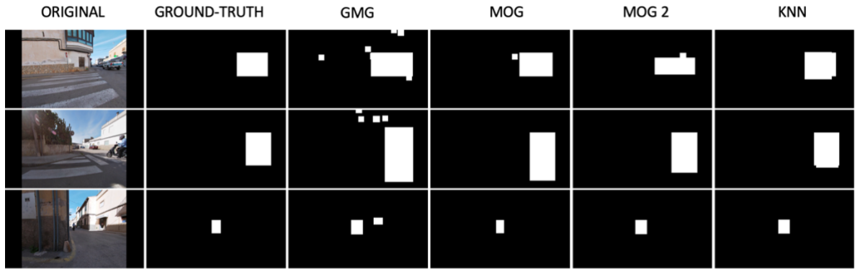
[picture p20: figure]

Il·lustració 24: Comparació de les mascares dels algoritmes de background Subtraction

7.3.1 SELECCIÓ DE L’ALGORITME

A la taula 1es presenten els resultats obtinguts de l’avaluació dels diferents algoritmes de Background Subtraction. Per l’avaluació de cadascun dels algoritmes s’han utilitzat les màscares -segmentades manualment i descrites amb anterioritat- com a ground thruth. La taula presenta les mesures usades per a l’avaluació que s’han presentat a la metodologia: Precisió (rati píxels classificats correctament), Sensitivitat (Positius vertaders respecte tots els positius), Especificitat ( Número de mostres classificades com a negatives respecte de totes les mostres), F-1 (relació entre sensitivitat i precisió) i temps de processat (temps que es triga a processar cada frame)

Taula 1: Avaluació algoritmes de Backgroud Subtraction

Algoritme BS | Precisió | Sensitivitat | Especificitat | Valor F-1 | Temps | de
processat (s)
KNN | 0,983 | 0,883 | 0,922 | 0,853 | 0,0015
MOG | 0,913 | 0,599 | 0,736 | 0,543 | 0,003
MOG2 | 0,973 | 0,785 | 0,711 | 0,648 | 0,002
GMG | 0,950 | 0,375 | 0,931 | 0,474 | 0,0025

Treball de final de grau

A la taula 1 es veu que tots els algoritmes tenen un valor elevat de precisió, però com s’ha comentat abans, aquest valor es pot veure afectat per les dades no balancejades. Tenint en compte això és necessari avaluar la resta de mesures.

Al ser un projecte pel qual allò més important és que es detectin correctament els positius, és a dir, els objectes que es trobin en moviment, la sensitivitat és un paràmetre que s’ha de tenir en compte. Aquesta necessitat es deu al fet que una detecció errònia podria acabar provocant un accident, per exemple, en el cas que no es detectés un cotxe que vingués pel costat i -com a conseqüència de no rebre cap notificació, es podruís una col·lisió. En aquest sentit, el cost de cometre un error de tipus FN vs un del tipus FP és molt major.

D’acord amb això es pot descartar l’algoritme MOG i el GMG, ja que no detecten correctament aquests objectes. L’algoritme GMG té una especificitat molt elevada però a l’aplicació d’ús d’aquest projecte no és tan importat. De fet,si es mira el valor-F és el més baix de tots els algoritmes.

Finalment entre el MOG2 i el KNN, s’ha determinat que el KNN és l’algoritme que té un millor funcionament de tots els que s’han provat, tenint en compte que el valor F-1 és més elevat que la resta a més de tenir l’especificitat més gran. Els valors obtinguts en aquesta avaluació concorden amb els obtinguts per altres estudis realitzats [38],[13].

7.3.2 K-NN BACKGROUND SUBTRACTION I POSTPROCESSAT

L’avaluació d’aquest algoritme ha tingut lloc en el propi procés de selecció descrit en l’apartat anterior. Això es deu al fet que, en tots els casos anteriors, les imatges usades per a l‘avaluació havien passat per totes les passes del processat des de l’obtenció de la imatge al bounding box.

En qualsevol cas, presentem a continuació una breu valoració qualitativa dels procés. A les següents imatges es presenten diferents situacions a les quals s’ha aplicat l’algoritme de Background Subtraction. En algunes de les imatges presentades es pot veure com s’aïllen els elements estàtics de les imatges, com són els cotxes aparcats i altres elements que no interessa que es reconeguin. En altres casos es veu com es detecten elements que estan en moviment i potser no haurien de ser detectats, com ara reflexos i ombres.

Treball de final de grau

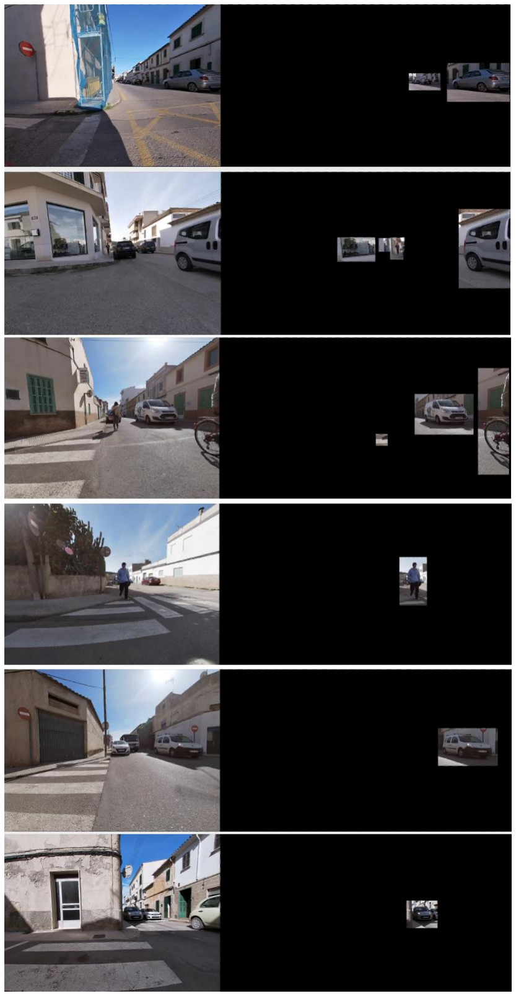
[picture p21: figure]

Il·lustració 25: Exemples del Background Subtraction aplicat

Treball de final de grau

7.4 DETECCIÓ D’OBJECTES

7.4.1 SELECCIÓ DE L’ALGORITME

En aquest apartat es donarà una explicació al perquè s’ha seleccionat aquest mètode de detecció d’objectes, a més dels avantatges que aquest suposa sobre els altres. Prèviament a la decisió d’usar la xarxa Mobilenet-SSD v2 s’han fet proves amb el detector d’objectes YOLO (You Only Look Once) [22]: aquestes dues xarxes són les més usades per sistemes encastats. Com ja s’ha comentat abans a la recol·lecció de dades del vehicle, per tal de poder detectar vehicles que es desplacin a una velocitat 60 km/h, l’adquisició d’imatges ha de tenir lloc a un ritme superior als 16 FPS. Tenint això en compte, l’algoritme YOLOv3 ha de ser descartat, ja que només permetria reconèixer objectes que es desplacessin a 18 km/h. A la taula 2, es comparen les velocitats d’execució (en FPS) dels algoritmes i les mAP⁴ de cada algoritme.

[39]

Taula 2: Comparació resultats algoritmes detecció d’objectes [35],[11],[22], [40]

Algoritme | Velocitat d’execució (FPS) | mAp | Dataset
YOLOv3 | 5 | 0.7423 0,606 | VOC2007 [41] MS-COCO [34]
Tiny YOLO | 25 | 0,331 | MS-COCO
MobileNet-SSD v2 | 39 | 0,727 0,68 | VOC0712 MS-COCO

Un altre factor molt important és la correcta detecció dels objectes, en aquest cas vehicles i persones. La detecció errònia d’aquests podria provocar un accident. Tenint en compte les dades de la taula, i comparant les dues xarxes restants, es determina que el millor algoritme per aquest cas d’ús és la xarxa MobileNet-SSD v2, atès que presenta una millor precisió que el TinyYOLO.

4 mAP: Es tracta de la mean Average Precision(mAP), una mesura molt usada per a l’avaluació d’algoritmes de reconeixement d’objectes. L’Average Precision (AP) es calcula trobant l’àrea sota la corba de precisió i recall. La mAP és la mitjana de les AP de totes les classes.

Treball de final de grau

7.4.2 DETECCIÓ D’OBJECTES AMB MOBILENET -SSD V2

Els resultats de processament obtinguts per a la detecció d’objecte s’han vist afectats per diferents elements.

En primer lloc la velocitat d’execució (en FPS) obtinguts a la Jetson Nano es veuen reduïts en comparació als obtinguts a l’ordinador, a causa de la capacitat més limitada de processament. El fet d’usar una GUI incrementa aquesta disminució en la velocitat d’execució passant de 15 FPS a 10 FPS. Això passa a conseqüència de què la GUI es queda esperant l’entrada d’un esdeveniment (event), fet que provoca un petit retard i per tant una reducció de velocitat. A la Taula 3, es poden observar les diferent velocitats d’execució en les diferents situacions. Un altre factor que provoca la reducció de velocitat és a conseqüència d’usar una bateria portàtil com a font d’alimentació. Aquest fet, fa que l’algoritme deixi de ser funcional, a causa de que l’elevada pèrdua de frames. Té tal efecte que inclús la detecció de persones és impossible. Però com s’ha comentat a l’apartat de metodologia únicament s’ha usat aquets mètode d’alimentació, degut a la limitació del vehicle usat per les proves. En el cas que fos incorporat a un vehicle es faria amb l’alimentació de 10W.

Taula 3: Velocitat de processament del reconeixement d'objectes en diferents situacions

Dispositius

| Macbook pro, 16 GB Ram i processador i5 | Jetson Nano (alimentació 10W) amb GUI, endollat a la corrent | Jetson Nano (alimentació 10W) sense GUI, endollat a la corrent | Jetson Nano (alimentació 5W) endollat a la corrent | Jetson Nano (alimentació 5W) enxufat al power bank
FPS | 20 | 10 | 15 | 6 | 2

L’avaluació de la detecció d’objectes s’ha dut a terme amb el conjunt de 300 imatges del datat set. Aquestes han estat inspeccionades visualment i s’ha establer si hi havia algun dels objectes a detectar o no. Cada classe s’ha etiquetat com si es tractes d’un problema binari. Per al criteri d’avaluació s’han considerat tres cassos, que permetran el càlcul de la precisió i el recall. El primer cas, seria que el resultat de l’algoritme i el valorat visualment coincideixin, aquest seria PV. En cas de què el resultat de l’algoritme indiqui que l’objecte detectat pertany a una classe errònia serà FP i finalment si l’objecte està present a la imatge però no

Treball de final de grau

ha estat detectat s’etiquetarà com a FN. Cal esmentar que hi ha dues classes que no han pogut ser avaluades per la falta de dades. A la Taula 4 es mostra el numero de mostres per cada classe que hi ha dins del data set de 300 imatges, i el nombre de PV, FP i FN per cada una d’elles. A la taula s’observa que la majoria de imatges pertanyen a les classes persona i cotxe.

Taula 4: Numero de mostres per classe, i valors de TP, FP i FN

Nombre de mostres amb l’objecte
present | PV | FP | FN
Cotxe | 128 | 78 | 6 | 50
Motocicleta | 24 | 8 | 0 | 16
Persona | 122 | 80 | 10 | 42
Bicicleta | 0 | 0 | 0 | 0
Bus | 0 | 0 | 6 | 0

Amb els valors de PV, FP i FN, s’ha creat la següent taula on es poden veure els valors de precisió i recall obtinguts per cada classe.

Taula 5: Resultats avaluació reconeixement d'objectes

Precision | Recall
Cotxe | 0.92 | 0.68
Motocicleta | 1 | 0.33
Persona | 0.93 | 0.65
Bicicleta | | No es tenen suficients imatges
Bus | | No es tenen suficients imatges

Treball de final de grau

A la taula anterior es pot observar que el reconeixement es du a terme de manera molt precisa. Això indica que, de totes les deteccions que s’han fet, una gran part han estat correctes. En canvi, el recall ens indica que de totes les deteccions que hauria d’haver tingut el model, n’hi ha hagut un gran nombre que no s’han detectat. Després d’analitzar els resultats i revisar les imatges s’ha pogut detectar que el principal problema en els casos en què no s’ha detectat l’objecte, és a causa de la distància que es troba respecte a la càmera. L’algoritme comença a tenir problemes amb la detecció quan l’objecte es troba al voltant de 7 metres de la càmera, això pot ser un problema i requeriria una avaluació més profunda per veure si suposa que el sistema no sigui eficaç.

7.5 INTERFÍCIE D’USUARI I AVISOS

Un cop analitzades les dades, a continuació es presenten una sèrie d’imatges on es veu com els avisos lluminosos s’activen quan es detecta algun objecte reconegut. Cal recordar que únicament s’activa del costat que s’ha detectat l’objecte. Al primer exemple es veu com, al detectar-se una persona, s’activa el LED amb el símbol de persona. A la següent imatge es poden veure els dos LEDs actius simultàniament. I finalment a la darrera imatge es pot veure com està actiu un LED a cada costat de la pantalla.

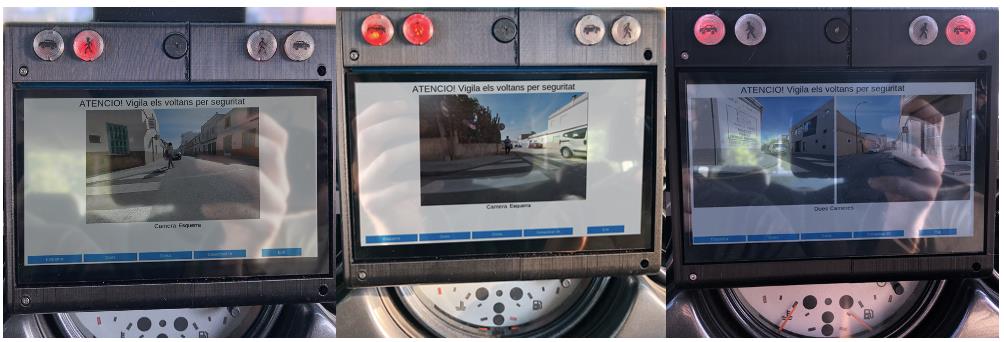
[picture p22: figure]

Il·lustració 26: Exemples dels avisos lluminosos en diferents situacions

Finalment, a la imatge 27 es presenta el dispositiu muntat al cotxe. Aquest s’ha enganxat al quadre de comandaments del cotxe amb velcro.

Treball de final de grau

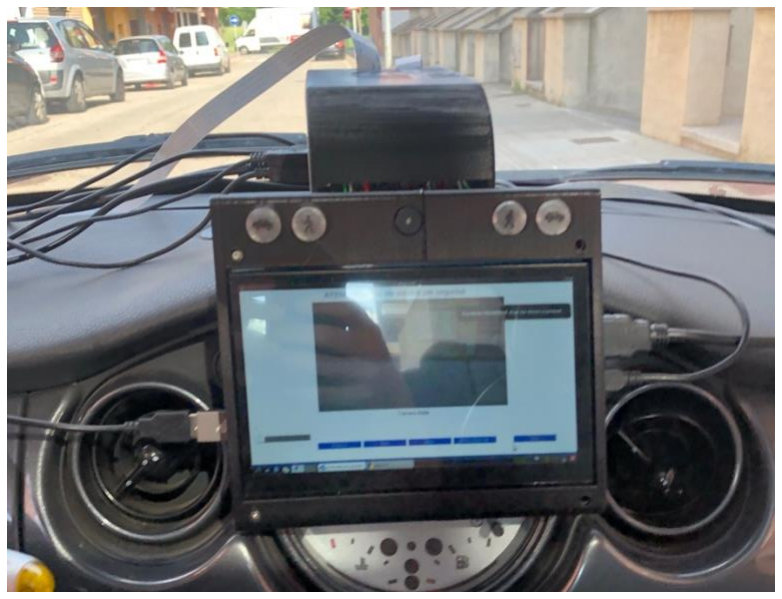
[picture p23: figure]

Il·lustració 27: Sistema ARGOS Cam muntat al cotxe

### 8. DISCUSSIÓ

La diferència de distància que el cotxe surt al carrer suposa una major seguretat vial pel fet de que no s’està envaint la via a la que es vol incorporar el conductor, fet que redueix el risc de col·lisió. La qualitat de les imatges mostrades per pantalla, tot i que no és d’alta qualitat, és suficient perquè es puguin reconèixer els objectes que es pretenia: vehicles i persones. Ara bé, en condicions adverses, com pot ser una pluja forta, boira o una zona mal il·luminada durant el vespre o a que la càmera quedi a contra llum, poden suposar que les imatges captades siguin inservibles i l’objecte no sigui detectat correctament. Aquestes adversitats podrien ser superades, tot i que ja es requeriria un estudi més complet per poder trobar un mètode adequat.

En relació al mòdul de Background Subtraction, l’algoritme resultant ha presentat un resultats que compleixen amb la seva funció d’aïllar els objectes estàtics com son els cotxes aparcats. Però el fet d’emmascarar els subjectes estàtics també pot portar problemes en alguns casos en que una persona es quedi estàtica, a la imatge 24, s’ha pogut veure un exemple. Si es dona el cas aquesta també serà emmascarada i no serà detectada per l’algoritme de detecció d’objectes. En altres casos també es detecten els reflexes, ja que, aquests es tradueixen en moviment en la imatge. Aquests no produeixen un efecte negatiu, únicament augmenten les zones detectades.

Treball de final de grau

Per poder solucionar el problema, de les persones que es queden estàtiques, s’hauria d’intentar modificar l’algoritme, per exemple, combinant-lo amb algun altre detector d’objectes per reconèixer únicament persones o fer us d’un algoritme de Semantic Segmentation com els que s’ha presentat a l’estat de l’art

Respecte del reconeixement d’imatge, s’ha demostrat que és possible aconseguir una detecció amb uns FPS adequats i amb una precisió elevada permetent detectar els objectes de forma correcta, sempre i quan funcioni amb una potencia de 10W i sigui alimentada a 5V 4A. El problema principal és que aquesta detecció no es pot dur a terme amb la placa seleccionada si es fa ús de la interfície gràfica, ja que aquesta redueix els FPS a la meitat passant a un valor inferior al que es desitjava. A més a més, els baixos resultats de recall obtinguts i els casos de FN observats durant l’etiquetatge, són un indicatiu de què s’hauria de millorar la xarxa neuronal per tal que pugui reconèixer els objectes a una major distancia.

Un altre punt a destacar és que en cas que un objecte que no estas dins les classes d’objectes mencionades, aquest no seria reconegut, i això podria provocar una situació perillosa. Un exemple podria ser: si una pilota es posés en mig del carrer aquesta no seria detectada, però al primer moment en què aparegués una persona al darrere aquesta sí que apareixeria. Un altre exemple, podria ser un animal que es creués en mig del carrer, aquest a no ser que anés seguit d’un objecte reconegut no es detectaria i no s’avisaria al conductor, fet que podria acabar provocant un accident. Vist aquets exemples pot ser seria convenient ampliar el nombre de classes detectades introduint objectes comuns que poden estar al mig de la carretera.

Treball de final de grau

### 9. CONCLUSIÓ

En conclusió amb la realització d’aquest projecte s’ha demostrat que és possible la fabricació d’un dispositiu, que fa ús de processament d’imatge, que permeti millorar la visibilitat a les cantonades i d’aquesta manera fent possible la reducció d’aquests tipus d’accidents.

Aquest dispositiu podria ser incorporat als sistemes que ja es troben integrats a la majoria dels cotxes d’avui en dia, com pantalles, càmeres i altres sensors que facilitarien la construcció d’aquest. En el cas ideal aquest podria passar a ser un nou ADAS que incorporessin els cotxes.

La part més problemàtica de tot el projecte ha estat la correcte configuració de la Jetson Nano, pel fet d’estar poc familiaritzat amb el sistema operatiu Linux i la instal·lació de paquets en aquest, a més de les incompatibilitats que s’han trobat amb les llibreries amb les que s’havia treballat prèviament. Un altre punt que ha donat problemes, ha està la dràstica reducció de FPS observada en passar el codi a la placa, a causa de la capacitat limitada de multiprocessament que ha presentat i la limitació de la potencia de processament, a causa de l’alimentació amb el power bank.

Els tres objectius proposats al principi del projecte han estat completats en la major part. L’únic que no ha pogut ser complert del tot, ha estat el de la integració completa del sistema al cotxe, però conegut la font del problema, es senzill de solucionar, alimentant la placa d’una manera més eficient.

En resum, perquè el sistema pogués ser incorporat en un cotxe com a part d’un nou sistema ADAS, aquest hauria de passar per una sèrie de millores. A continuació, es presenten unes possibles futures millores que es podrien aplicar al projecte perquè aquest pugui ser un nou sistema d’assistència al conductor.

9.1 FUTURES MILLORES

9.1.1 RECOL·LECCIÓ DADES DEL VEHICLE

En el cas de la integració dins un vehicle la lectura de la velocitat es faria de forma interna, fent que aquesta fos més precisa.

Treball de final de grau

9.1.2 CAPTURA D’IMATGES

Per exemple, pels dos primers es podria intentar usar la tecnologia sensor fusion, usada per alguns cotxes autònoms, que s’ha comentat a l’apartat d’estat de l’art. La solució consistiria a combinar la lectura de les càmeres i sensors de distància.

El segon problema, es podria intentar solucionar canviant el tipus de càmeres usades per càmeres de visió nocturna. Aquestes ja suposarien l’addició de sensors infrarojos per permetre la visibilitat.

9.1.3 SISTEMA ENCASTAT

La utilització d’una versió superior de la Jetson Nano, com podria ser la Jetson Nano Xavier NX, permetria una major velocitat de processament, millorant el rendiment del sistema en tots els escenaris.

La millora que seria més important realitzar seria la connexió de la placa a una font que tingues el voltatge i corrents adequats. La connexió directa a la bateria del cotxe amb un convertidor reductor de 12 a 5 V seria una de les millors opcions.

9.1.4 DETECCIÓ D’OBJECTES

Per a la millora d’aquesta secció es podria fer ús de tècniques de Transfer Learning, per al reentrenament de la xarxa neuronal usada, aplicades a la situació presentada el projecte, en la que la càmera està situada a la cantonada. A més a més també es podria entrenar amb imatges en situacions adverses com les que s’han presentat a l’apartat de resultats, per veure si s’obté una millora sense necessitat de canviar el hardware.

Treball de final de grau

### 10. BIBLIOGRAFIA

[1] | “El | grimorio | de | bestias: | Argos.”
https://grimoriodebestias.blogspot.com/2014/04/argos.html | (accessed | May | 11,
2021).
[2] DGT, “Tablas estadísticas 2019,” 2019. Accessed: May 15, 2021. [Online]. Available: https://www.dgt.es/es/seguridad-vial/estadisticas-e-indicadores/accidentes-30dias/tablas-estadisticas/2019/.
[3] | “ADAS: | Past, | present | and | future | | | Vehicle | Service | Pros.”
https://www.vehicleservicepros.com/service-repair/diagnostics-and-drivability/article/21198482/adas-past-present-and-future (accessed May 11, 2021).
[4] “What are car surround view cameras, and why are they better than they need to be? - ExtremeTech.” https://www.extremetech.com/extreme/186160-what-are-surround-view-cameras-and-why-are-they-better-than-they-need-to-be (accessed May 11, 2021).
[5] “LIDAR vs. Camera — Which Is The Best for Self-Driving Cars? | by Vincent Tabora |
0xMachina | Medium.” https://medium.com/0xmachina/lidar-vs-camera-which-is-
the-best-for-self-driving-cars-9335b684f8d (accessed May 11, 2021).
[6] “Taller del automovil – Historia del OBD.” https://ibtaller.com/historia-del-obd/(accessed May 11, 2021).
[7] “Sistema OBD de un coche: todo lo que debes saber - canalMOTOR.” https://www.motor.mapfre.es/consejos-practicos/consejos-de-mantenimiento/como-funciona-el-sistema-obd/ (accessed May 11, 2021).
[8] “Comparing the Different Interface Standards for Embedded Vision,” 14/11/18. https://www.automate.org/blogs/comparing-the-different-interface-standards-for-embedded-vision (accessed May 12, 2021).
[9] “Beginner’s Guide: Choose the Right Camera Modules for Your Raspberry Pi or Jetson Nano Dev Kit.” https://www.arducam.com/choose-camera-modules-raspberry-pi-jetson-nano-guide/ (accessed May 12, 2021).
[10] D. Reifs, “Sistemes Encastats.”
[11] “Jetson Nano: Deep Learning Inference Benchmarks | NVIDIA Developer.”
https://developer.nvidia.com/embedded/jetson-nano-dl-inference-benchmarks (accessed Apr. 21, 2021).
[12] | “Buy | a | Raspberry | Pi | 4 | Model | B | – | Raspberry | Pi.”
https://www.raspberrypi.org/products/raspberry-pi-4-model-b/ (accessed May 27,
| 2021).
[13] T. Trnovszký, P. Sýkora, and R. Hudec, “Comparison of Background Subtraction Methods on Near Infra-Red Spectrum Video Sequences,” in Procedia Engineering, Jan. 2017, vol. 192, pp. 887–892, doi: 10.1016/j.proeng.2017.06.153.
[14] D. Zeng, X. Chen, M. Zhu, M. Goesele, and A. Kuijper, “Background Subtraction with Real-time Semantic Segmentation.”

Treball de final de grau

[15] | “Semantic | Segmentation | - | MATLAB | & | Simulink.”
https://www.mathworks.com/solutions/image-video-processing/semantic-segmentation.html (accessed May 13, 2021).
[16] “What is LiDAR technology?” https://blog.generationrobots.com/en/what-is-lidar-technology/ (accessed Feb. 14, 2021).
[17] “Deep Learning: qué es y por qué va a ser una tecnología clave en el futuro de la inteligencia artificial.” https://www.xataka.com/robotica-e-ia/deep-learning-que-es-y-por-que-va-a-ser-una-tecnologia-clave-en-el-futuro-de-la-inteligencia-artificial (accessed May 13, 2021).
[18] K. L. Masita, A. N. Hasan, and T. Shongwe, “Deep learning in object detection: A review,” Aug. 2020, doi: 10.1109/icABCD49160.2020.9183866.
[19] D. Sarkar and Towards Data Sience, “A Comprehensive Hands-on Guide to Transfer
Learning with Real-World Applications in Deep Learning | by Dipanjan (DJ) Sarkar |
Towards | Data | Science,” | 14/11/18. | https://towardsdatascience.com/a-
comprehensive-hands-on-guide-to-transfer-learning-with-real-world-applications-in-deep-learning-212bf3b2f27a (accessed May 13, 2021).
[20] R. Girshick, J. Donahue, T. Darrell, and J. Malik, “Rich feature hierarchies for accurate object detection and semantic segmentation Tech report (v5).” Accessed: May 13, 2021. [Online]. Available: http://www.cs.berkeley.edu/˜rbg/rcnn.
[21] S. Ren, K. He, R. Girshick, and J. Sun, “Faster R-CNN: Towards Real-Time Object Detection with Region Proposal Networks.” Accessed: May 13, 2021. [Online]. Available: http://image-net.org/challenges/LSVRC/2015/results.
[22] “YOLO: Real-Time Object Detection.” https://pjreddie.com/darknet/yolo/ (accessed Apr. 21, 2021).
[23] W. Liu et al., “SSD: Single Shot MultiBox Detector.” Accessed: Apr. 21, 2021. [Online]. Available: https://github.com/weiliu89/caffe/tree/ssd.
[24] “SSD object detection: Single Shot MultiBox Detector for real-time processing | by
Jonathan Hui | Medium.” https://jonathan-hui.medium.com/ssd-object-detection-
single-shot-multibox-detector-for-real-time-processing-9bd8deac0e06 (accessed May 13, 2021).
[25] “Elm327-interfaz De Cable Usb V1.5 Para Diagnóstico De Coche,Compatible Con Todos Los Protocolos Obd2 Para Windows Elm 327,Escáner Obd Usb - Buy Elm327 Usb
V1.5,Usb | Cable | Interface,Obd | Scanner | Product | on | Alibaba.com.”
https://spanish.alibaba.com/product-detail/elm327-usb-v1-5-car-diagnostic-usb-cable-interface-supports-all-obd2-protocols-for-windows-elm-327-usb-obd-scanner-6973707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 (accessed May 27, 2021).
[26] “Getting Started - python-OBD.” https://python-obd.readthedocs.io/en/latest/(accessed May 14, 2021).
[27] “Raspberry Pi Camera Module V2.1 | Módulo de cámara Raspberry Pi, interfaz CSI-2,
resolución 3280 x | 2464 | píxeles, 30fps | | | RS | Components.” https://es.rs-
online.com/web/p/camaras-para-raspberry-pi/9132664/ (accessed May 17, 2021).

Treball de final de grau

[28] “opencv_contrib/evaluation.py at master · opencv/opencv_contrib · GitHub.” https://github.com/opencv/opencv_contrib/blob/master/modules/bgsegm/samples/evaluation.py (accessed Apr. 18, 2021).
[29] “Background Subtraction with OpenCV and BGS Libraries | Learn OpenCV.”
https://learnopencv.com/background-subtraction-with-opencv-and-bgs-libraries/(accessed Apr. 18, 2021).
[30] Z. Zivkovic and F. Van Der Heijden, “Efficient adaptive density estimation per image pixel for the task of background subtraction,” Pattern Recognit. Lett., vol. 27, no. 7, pp. 773–780, May 2006, doi: 10.1016/j.patrec.2005.11.005.
[31] | “OpenCV: | cv::BackgroundSubtractorKNN | Class | Reference.”
https://docs.opencv.org/4.5.2/db/d88/classcv_1_1BackgroundSubtractorKNN.html (accessed Apr. 18, 2021).
[32] | “KNN | Algorithm | - | Finding | Nearest | Neighbors | - | Tutorialspoint.”
https://www.tutorialspoint.com/machine_learning_with_python/machine_learning_with_python_knn_algorithm_finding_nearest_neighbors.htm (accessed May 14, 2021).
[33] | “OpenCV: | Morphological | Transformations.”
https://docs.opencv.org/4.5.2/d9/d61/tutorial_py_morphological_ops.html (accessed Apr. 18, 2021).
[34] “COCO - Common Objects in Context.” https://cocodataset.org/#home (accessed Apr. 21, 2021).
[35] “GitHub - chuanqi305/MobileNet-SSD: Caffe implementation of Google MobileNet SSD detection network, with pretrained weights on VOC0712 and mAP=0.727.” https://github.com/chuanqi305/MobileNet-SSD (accessed Apr. 21, 2021).
[36] A. G. Howard et al., “MobileNets: Efficient Convolutional Neural Networks for Mobile Vision Applications.”
[37] “MobileNet version 2.” https://machinethink.net/blog/mobilenet-v2/ (accessed Apr.
| 21, 2021).
[38] “[OpenCV Actual Combat] 43 Use OpenCV for background segmentation -Programmer Sought.” https://www.programmersought.com/article/10826881459/(accessed Apr. 18, 2021).
[39] “mAP (mean Average Precision) might confuse you! | by Shivy Yohanandan |
Towards Data Science.” https://towardsdatascience.com/map-mean-average-precision-might-confuse-you-5956f1bfa9e2 (accessed May 31, 2021).
[40] “GitHub - taehoonlee/tensornets: High level network definitions with pre-trained weights in TensorFlow.” https://github.com/taehoonlee/tensornets (accessed Apr. 21,
| 2021).
[41] | “The | PASCAL | | Visual | Object | Classes | | Homepage.”
http://host.robots.ox.ac.uk/pascal/VOC/ (accessed Apr. 21, 2021).
[42] M. Grundmann, V. Kwatra, and I. Essa, “Auto-directed video stabilization with robust L1 optimal camera paths,” Proc. IEEE Comput. Soc. Conf. Comput. Vis. Pattern

Treball de final de grau

Recognit., no. 1, pp. 225–232, 2011, doi: 10.1109/CVPR.2011.5995525.

Treball de final de grau

### 11. ANNEX

11.1 CANTONADES

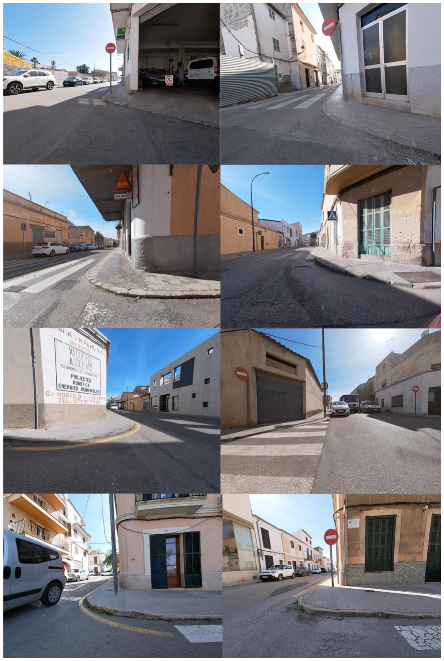
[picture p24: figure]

Annex 1: Més exemples de cantonades on es pot aplicar el projecte

Treball de final de grau

11.2 CODI FET AMB PYTHON

Com s’ha comentat a la metodologia el codi consta de dues parts. La primera es una classe creada per controlar els algoritmes de les càmeres i la segona es l’encarregada de gestionar la GUI, la lectura del OBD i la integració de les càmeres al sistema.

11.2.1 CLASSE PROCESSAT D’IMATGE

#la part del codi d'execució en paralel de les càmeres esta basada en el codi següent # MIT License

# Copyright (c) 2019,2020 JetsonHacks

# See license

# A very simple code snippet

# Using two CSI cameras (such as the Raspberry Pi Version 2) connected to a

# NVIDIA Jetson Nano Developer Kit (Rev B01) using OpenCV

# Drivers for the camera and OpenCV are included in the base image in JetPack 4.3+

# This script will open a window and place the camera stream from each camera in a window # arranged horizontally.

# The camera streams are each read in their own thread, as when done sequentially there

# is a noticeable lag

# For better performance, the next step would be to experiment with having the window display # in a separate thread

#Importació de llibreries

from threading import Thread import threading
import cv2 as cv, cv2
import time
import numpy as np
import os
import RPi.GPIO as GPIO
import jetson.inference as inference import jetson.utils as utils

#crea clase per definir la camara

class vStream:
#inicialitzacio clase, entrar paramteres variables

def __init__(self, xarxa, width, height,placa ,pin_led_persona,pin_led_cotxe, pin_buzzer): #parametres de la camara (font, ample i alçada)

#GPIO#

#definicio parametres necessaris per els pins GPIO self.placa = placa

Treball de final de grau

self.pin_led_persona = pin_led_persona self.pin_led_cotxe = pin_led_cotxe
self.pin_buzzer=pin_buzzer
#definició dels pins com a output i es deixen apagats self.placa.setup(self.pin_led_cotxe, self.placa.OUT, initial=self.placa.LOW) self.placa.setup(self.pin_led_persona, self.placa.OUT, initial=self.placa.LOW) self.placa.setup(self.pin_buzzer, self.placa.OUT, initial=self.placa.LOW) self. marge_frames = 5 #numero de frames abans de cambiar estat GPIO

#Parametres càmera#

#definició tamany del frame capturat

self.width = width
self.height = height
self.capture = None
# Darrer frame agafat imatge self.frame = None

self.grabbed = False
self.running = True

#Rexoneixemnet d'objectes#

self.net = xarxa
self.thr = 0.5 # threshold, 0.5 valor per defecte
# definició dels noms de les classes que es reconeixeran

self.clases = ['background', 'truck', 'bicycle', 'bus','car','motorbike','person'] self.classNames = ['person']
self.classVehicle = ['bicycle', 'truck', 'bus', 'car', 'motorbike']
#Parametres de control de l'estat dels GPIO durant el reconeixement self.led_persona_On = False

self.led_vehicle_On = False
self.detectat_persona = False
self.detectat_vehicle = False
self.contador_detectats_persona = 0 # conta els cops que es detecten persones self.contador_no_detectats_persona = 0
self.contador_detectats_vehicle = 0 # conta els cops que es detecten vehicles self.contador_no_detectats_vehicle = 0

#Background Subtraction#

self.aument_quadre = 15 #valor que s'augmenta el bounding box obtingut self.color = (255, 255, 255)
#creació backgroun Subtraction i ajust de parametres

self.fgbg = cv2.createBackgroundSubtractorKNN() self.fgbg.setHistory(100)
self.fgbg.setNSamples(10)
self.fgbg.setkNNSamples(3)

#definicio dels kernels usats

self.kernel = cv2.getStructuringElement(cv2.MORPH_CROSS, (5, 5)) self.kernel1 = cv2.getStructuringElement(cv2.MORPH_ELLIPSE, (7, 7))

#Thread#

Treball de final de grau

#parametres per el control del thread self.read_thread = None

self.read_lock = threading.Lock() self.running = False

#Funico per inicialitzar la càmera

def open(self, gstreamer_pipeline_string):
try:
# el controlador de vídeo es gstramer

self.capture = cv2.VideoCapture(gstreamer_pipeline_string, cv2.CAP_GSTREAMER) self.grabbed, self.frame = self.capture.read()

except RuntimeError: #avisa si hi ha un error intentant obrir la càmera
self.capture = None
print("Imposible obrir camera")
print("Pipeline: " + gstreamer_pipeline_string)
return

#Funcio per iniciar el thread, crida la funcio que agafa nous frames def start(self):

if self.running:
print("Ja s'esta capturant vídeo")
return None

if self.capture != None:
self.running = True
self.read_thread = threading.Thread(target=self.updateCamera) self.read_thread.daemon = True
self.read_thread.start()
return self

#funcio per aturar el thread, necessaria per fer neteja quan es tanca el programa def stop(self):

self.running = False
self.read_thread.join()

#Funció per actualitzar la càmera i agafar nous frames, es cridada per el thread def updateCamera(self):

while self.running:
try:
grabbed, frame = self.capture.read() with self.read_lock:
self.grabbed = grabbed
self.frame = frame
try:
self.frame2 = cv2.resize(self.frame, (300, 300)) # redimensiona el frame

except Exception as err: #comprovació d'errors
print("falla captura camara", err)

Treball de final de grau

except RuntimeError:
print("No s'ha pogut llegir la càmera")

# Funció per obtenir el frame sense cap tipus de processament, manté parats els GPIO def getFrame(self):

print("frame")
self.placa.output(self.pin_led_cotxe, self.placa.LOW) self.placa.output(self.pin_led_persona, self.placa.LOW) self.placa.output(self.pin_buzzer, self.placa.LOW) return self.frame2

#Funcio per aplicar el background susbtraction

def Background_Subtraction(self):
try:
self.blur= cv2.GaussianBlur(self.frame2, (15, 15), 0) # Difumina l'imatge
self.fgmask = self.fgbg.apply(self.blur)# Calcual la mascara de fons
_, self.binary = cv2.threshold(self.fgmask, 50, 255, cv2.THRESH_BINARY) # Asegura que la mascara sigui binaria
self.open = cv2.morphologyEx(self.binary, cv2.MORPH_OPEN, self.kernel) # redueix el soroll de la imatge
self.close= cv2.morphologyEx(self.open, cv2.MORPH_CLOSE, self.kernel1) # fa que la mascara quedi mes neta, tanca forats
self.dilate = cv2.morphologyEx(self.close, cv2.MORPH_DILATE, self.kernel1) # expandeix la mascara

#primera detecció de contorns i unica en cas de que hi hagi un sol contorn self.contours, self.hierarchy = cv.findContours(self.dilate, cv.RETR_TREE, cv.CHAIN_APPROX_SIMPLE)

self.contours_poly = [None] * len(self.contours)
self.boundRect = [None] * len(self.contours)
for self.i, self.c in enumerate(self.contours):
self.contours_poly[self.i] = cv.approxPolyDP(self.c, 3, True)
self.boundRect[self.i] = cv.boundingRect(self.contours_poly[self.i])

self.drawing = np.zeros((self.frame2.shape[0], self.frame2.shape[1], 3), dtype=np.uint8)

for self.i in range(len(self.contours)):
cv.rectangle(self.drawing, ((int(self.boundRect[self.i][0]) - self.aument_quadre), (int(self.boundRect[self.i][1])) - self.aument_quadre), ((int(self.boundRect[self.i][0] + self.boundRect[self.i][2]) + self.aument_quadre), (int(self.boundRect[self.i][1] + self.boundRect[self.i][3])) + self.aument_quadre), self.color, cv2.FILLED)

self.draw = cv2.cvtColor(self.drawing, cv2.COLOR_BGR2GRAY)

# segona detecció de contorns, serveix per unificar la mascara en cas de que hi hagi alguns requadres en contacte

self.contours_, self.hierarchy_ = cv.findContours(self.draw, cv.RETR_TREE, cv.CHAIN_APPROX_SIMPLE)

Treball de final de grau

self.contours_poly = [None] * len(self.contours_)
self.boundRect = [None] * len(self.contours_)
self.tamany = 20 #filtra els contorns oer la mida
self.pasa_filtro = [] # lista de contornos que superan el area deseada for self.j, self.co in enumerate(self.contours_):
self.area = cv2.contourArea(self.co)
if self.area > self.tamany:
self.pasa_filtro.append(self.j)
self.contours_poly[self.j] = cv.approxPolyDP(self.co, 3, True)
self.boundRect[self.j] = cv.boundingRect(self.contours_poly[self.j])

self.drawing_ = np.zeros((self.frame2.shape[0], self.frame2.shape[1], 3), dtype=np.uint8)

#filtre per veure si s'aplica la segona detecció de contorns

if len(self.contours_) > 0:
for self.h in self.pasa_filtro:
cv.drawContours(self.drawing_, self.contours_poly, self.h, self.color) cv.rectangle(self.drawing_,
((int(self.boundRect[self.h][0]) - self.aument_quadre), (int(self.boundRect[self.h][1])) - self.aument_quadre), \ ((int(self.boundRect[self.h][0] + self.boundRect[self.h][2]) + self.aument_quadre), (int(self.boundRect[self.h][1] + self.boundRect[self.h][3])) + self.aument_quadre), self.color, cv2.FILLED)

self.res_box = cv2.bitwise_and(self.frame2, self.frame2, mask=cv2.cvtColor(self.drawing_, cv2.COLOR_BGR2GRAY)) else:
self.res_box = cv2.bitwise_and(self.frame2, self.frame2, mask=cv2.cvtColor(self.drawing, cv2.COLOR_BGR2GRAY))

return self.res_box

except Exception as fallo: #comprova errors print("error background Subtraction ", fallo)

#funcio per el reconeixement d'objectes amb el background Subtraction aplicat def reconocimiento_con_bg(self):

try:
#aplica background Subtraction

self.res_box=self.Background_Subtraction()
self.backgroud_resized= cv2.resize(self.res_box, (300, 300)) #reescalat de la imateg self.copia_frame = self.frame2.copy()
self.backgroud_resized = cv2.cvtColor(self.backgroud_resized, cv2.COLOR_BGR2RGBA)

# aplicació de la funcio per transformar imatge al format cuda self.backgroud_resized = utils.cudaFromNumpy(self.backgroud_resized)

self.cols = self.backgroud_resized.shape[1]
self.rows = self.backgroud_resized.shape[0]
self.detections = self.net.Detect(self.backgroud_resized) #funcio de reconeixement optimitzada amb cuda

Treball de final de grau

self.detectat_persona = False
self.detectat_vehicle = False
for self.detect in self.detections: #loop que recorre totes les deteccions obtingudes self.ID = self.detect.ClassID
self.item = self.net.GetClassDesc(self.ID)

self.confidence=self.detect.Confidence

if self.confidence > self.thr and (self.item in self.clases): #filtra per classe i per el threshold definit
print(self.item)

# Control dels GPIO
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

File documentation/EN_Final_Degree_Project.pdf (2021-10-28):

# FINAL DEGREE PROJECT

### SYSTEM TO REDUCE THE RISK OF ACCIDENTS AT STREET INTERSECTIONS (ARGOS[1] CAM)


Name: Ramon Angosto Artigues

Theme: Final Degree Project

Degree: Mechatronical engineering.

Professor: Laura Dempere-Marco

27 October de 2021

Mechatronics engineering

Final career work

Final career work

INDEX OF CONTENTS

Final career work

INDEX OF FIGURES

Figure 8: Representation of component connections with the Jetson Nano. The materials used for the project are: two Raspberry Pi v2 cameras, used for image capture; a touch screen to view images and interact with the user interface; an OBD reader used for vehicle data collection; a portable battery of the Xiaomi brand, with power capacity of 5v 2.6A;for GPIO connections, four LEDs and a buzzer are used (with the necessary additional

Figure 15: Stages of background subtraction a) Original image b) Blur c) KNN algorithm d)

Figure 16: Figurative representation of the separable depth wise layer (Source: Reference

Figure 18: GUI screens. A) Charging screen B) Screen while the vehicle is in motion C) Screen

Final career work

Figure 20: Parts of the screen housing, battery, and embedded system A) Embedded system, housing cover B) Base housing for embedded system, C) and D) Rear cover housing for
screen E) Screen and battery housing | 33
Figure 21: Right camera housing | 33
Figure 22: Example of the GUI with the car stopped and with the car in motion | 34
Figure 23: View of the cameras from the driver's point of view | 35
Figure 24: Comparison of masks of background subtraction algorithms | 36
Figure 25: Examples of applied background subtraction | 38
Figure 26: Examples of light warnings in different situations | 42
Figure 27: ARGOS cam system mounted on a car | 43

INDEX OF TABLES

Table 1: Evaluation of Background subtraction algorithms | 36
Table 2: Comparison of object detection algorithms [35],[11],[22], [40] | 39
Table 3: Object recognition processing speed in different situations | 40
Table 4: Sample number by class and TP, FP, and FN values | 41
Table 5: Results of object recognition evaluation | 41

Final career work
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

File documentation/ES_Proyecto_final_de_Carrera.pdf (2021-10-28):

# PROYECTO FINAL DE CARRERA

### SISTEMA PARA REDUCIR EL RIESGO DE ACCIDENTES EN INTERSECCIONES (ARGOS[1] CAM)


Nombre: Ramon Angosto Artigues

Tema: Proyecto final

Grado: Ingeniería mecatrónica.

Profesor/a: Laura Dempere-Marco

27 octubre de 2021

Ingeniería mecatrónica

Trabajo final de carrera

Trabajo final de carrera

ÍNDICE DE CONTENIDO

Trabajo final de carrera

ENDEX DEILUSTRACIONES
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

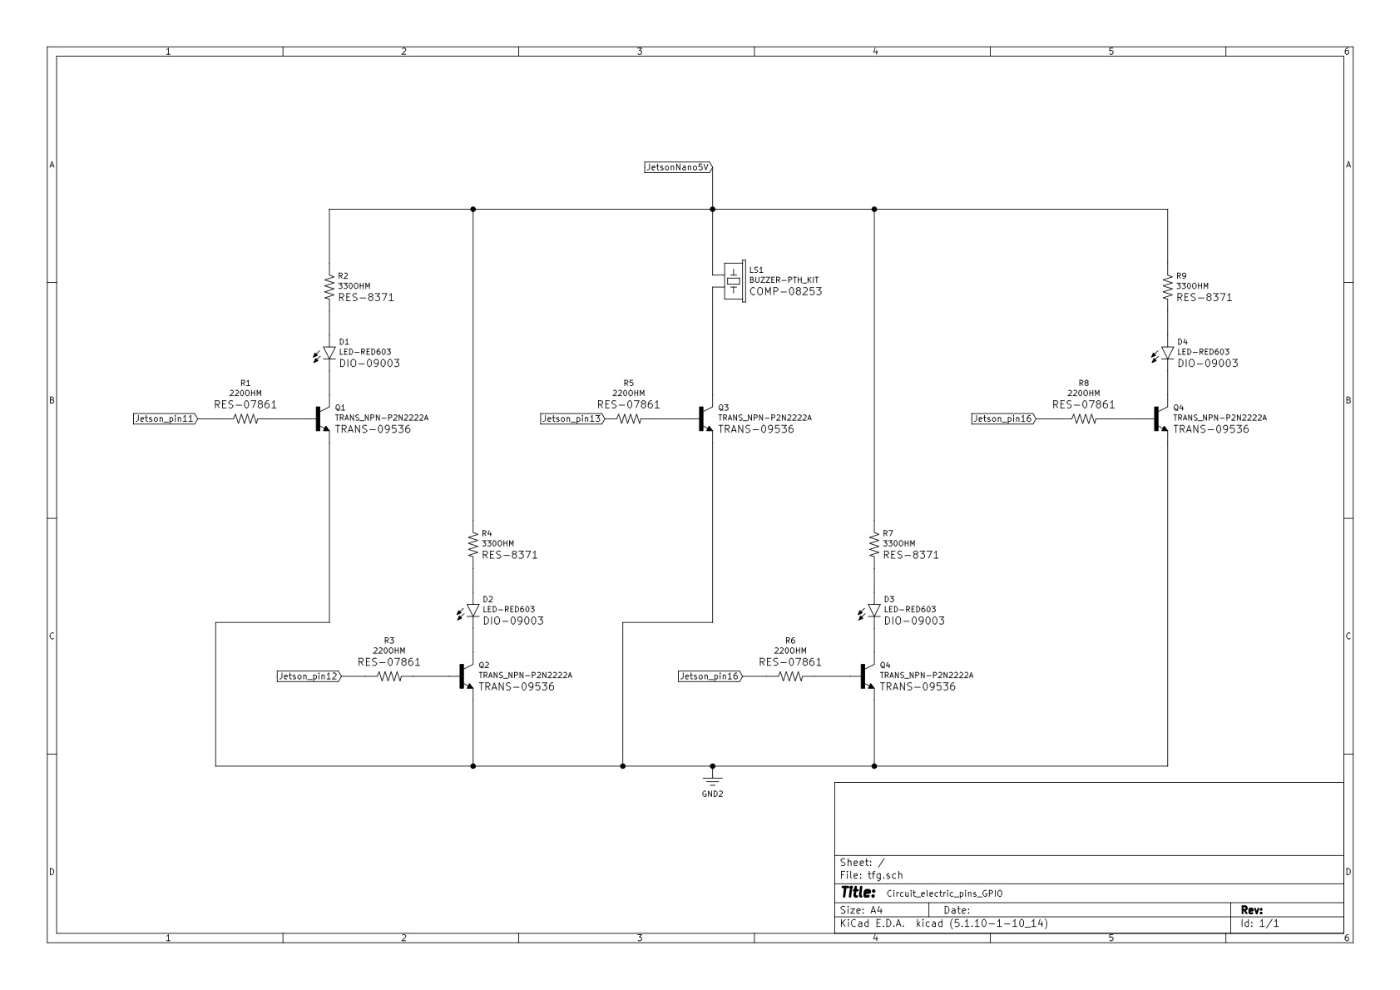
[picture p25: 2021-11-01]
Assambley/Electronics/electronic_circuit.jpg

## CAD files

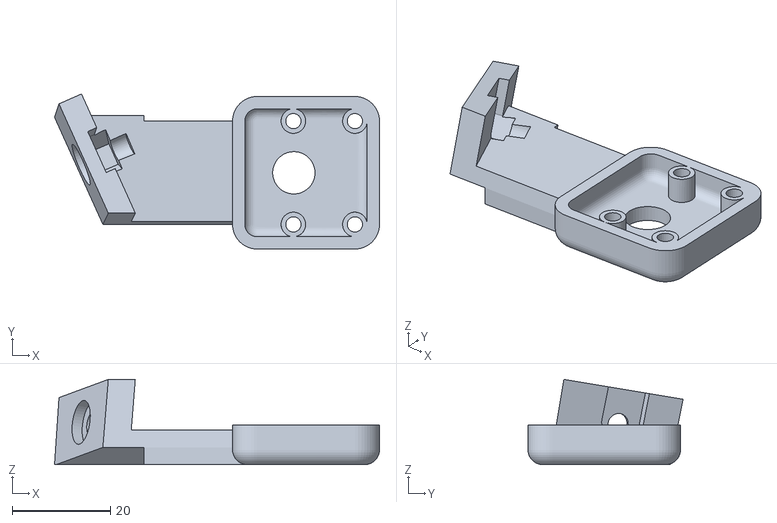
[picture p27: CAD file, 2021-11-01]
Assambley/3D/camera_case_front_right.stl
66.0 x 31.5 x 17.3

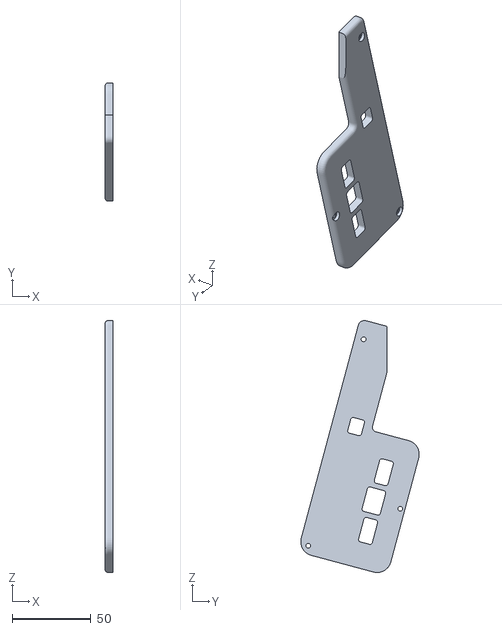
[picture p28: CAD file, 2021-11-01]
Assambley/3D/screen_case_side_cover.stl
5.00 x 75.1 x 159.8

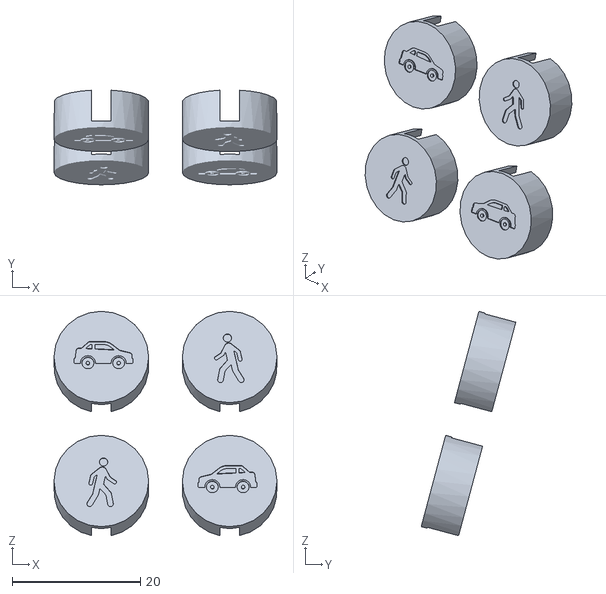
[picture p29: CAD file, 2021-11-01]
Assambley/3D/circles.stl
34.8 x 14.7 x 35.0

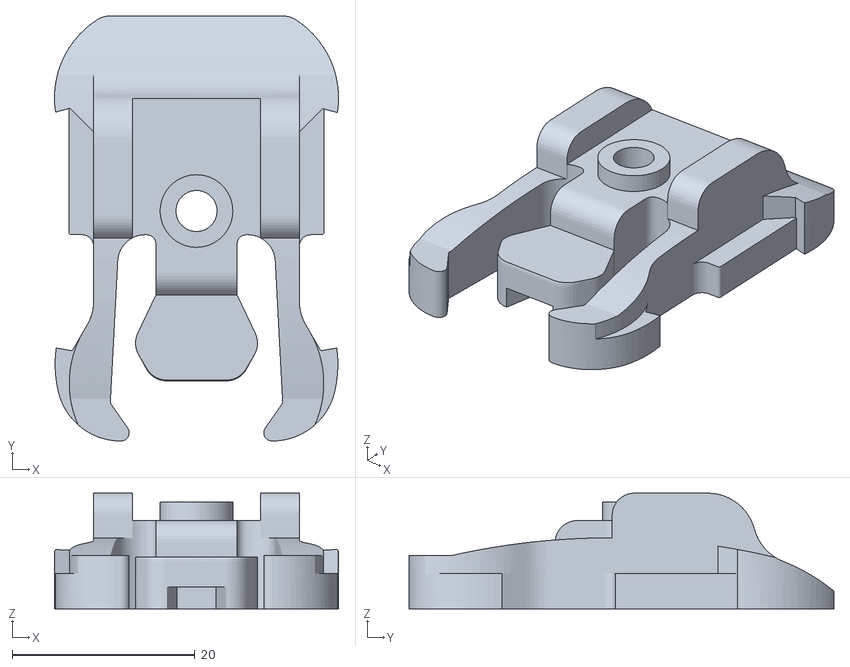
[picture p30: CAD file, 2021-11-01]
Assambley/3D/gopro_clip.stl
31.1 x 46.5 x 12.7

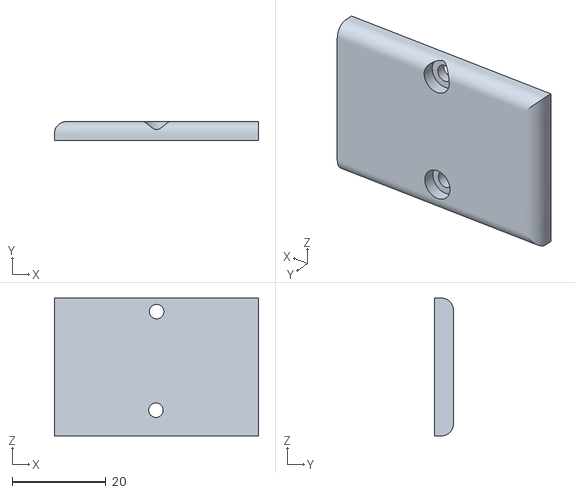
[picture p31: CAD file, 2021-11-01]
Assambley/3D/right_side_cover_screen_case.stl
43.5 x 4.00 x 29.4

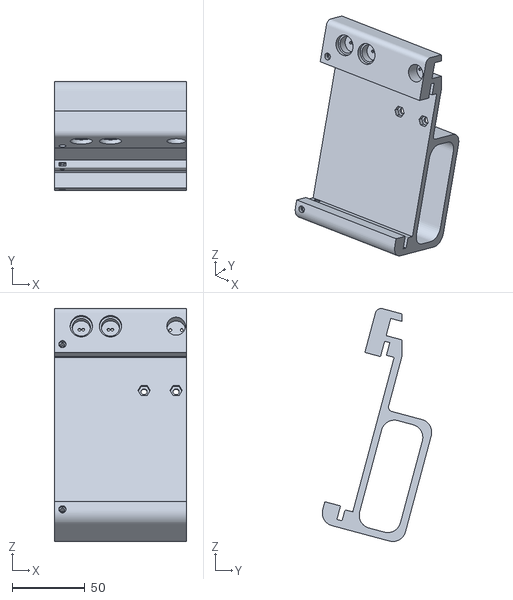
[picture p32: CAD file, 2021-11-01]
Assambley/3D/screen_case_2.stl
90.8 x 75.1 x 159.8

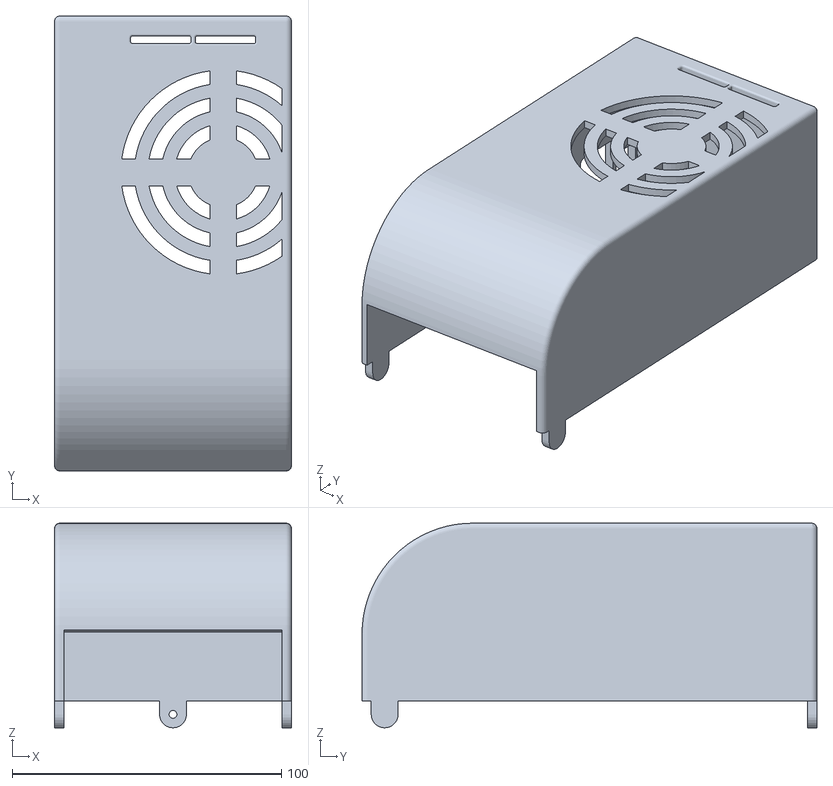
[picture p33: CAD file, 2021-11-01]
Assambley/3D/jetson_nano_case_cover.stl
88.0 x 168.9 x 76.0

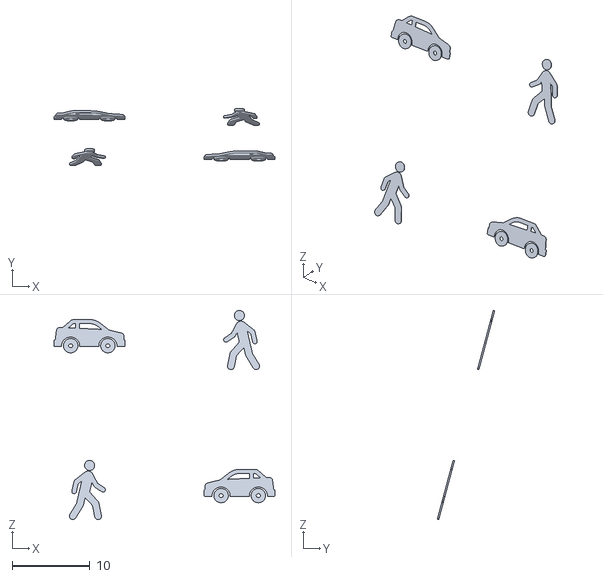
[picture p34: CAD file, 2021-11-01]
Assambley/3D/drawing.stl
28.5 x 7.40 x 27.0

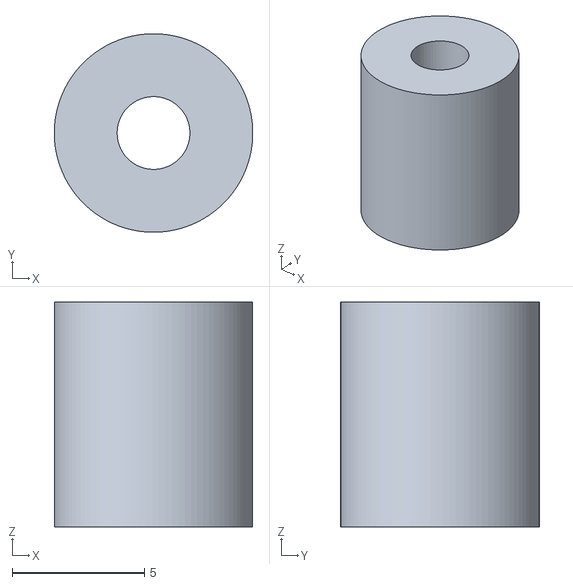
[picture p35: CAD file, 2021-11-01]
Assambley/3D/spacer.stl
7.50 x 7.50 x 8.50

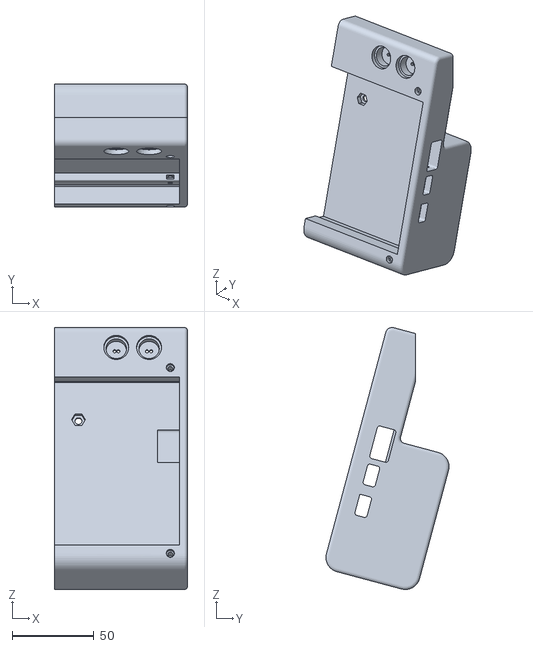
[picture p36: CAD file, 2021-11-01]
Assambley/3D/screen_case.stl
81.2 x 75.1 x 159.8

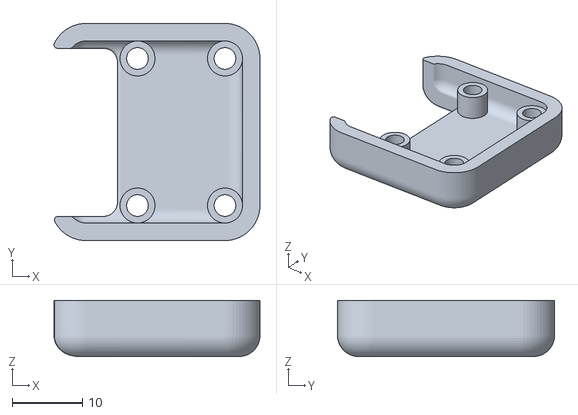
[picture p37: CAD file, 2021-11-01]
Assambley/3D/camera_case_back.stl
29.4 x 31.0 x 8.00

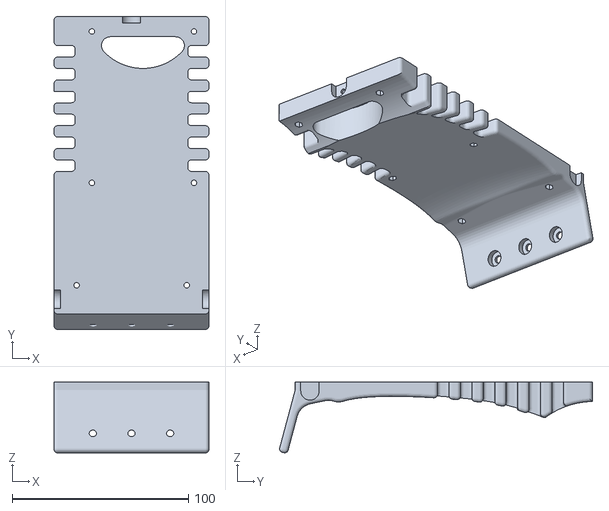
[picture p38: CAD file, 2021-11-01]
Assambley/3D/Jetson_nano_base.stl
88.0 x 177.8 x 40.2

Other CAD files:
Assambley/3D/camera_case_front_left.stl
Assambley/3D/left_side_cover_screen_case.stl

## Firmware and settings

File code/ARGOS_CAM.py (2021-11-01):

"""This code is meant to be used inside the car in combination with the obd reader
"""
# Import of necessary libraries
import PySimpleGUI as sg
from synchronized_cameras_recognition_modes import vStream, gstreamer_pipeline
import cv2
import time
from obd.protocols import ECU
from obd import OBDStatus
import obd
from queue import Queue
import threading
import Jetson.GPIO as GPIO
import jetson.inference as inference

# sets obd to detect all codes
obd.commands.TIME_SINCE_DTC_CLEARED.ecu = ECU.ALL
que = Queue()

# definition of global variables
speed = 0
high_speed = True
exit_ = True


# Avoid constant activation and deactivation of camera when moving slowly
speed_threshold = 5  # MODIFY TO REGULATE WHEN CAMERAS ARE ACTIVATED


# Function used to create a connection between the board and the OBD reader
def connect(n):
    n = "good"
    quick = True
    ports = obd.scan_serial()  # scans usb ports and return the available ones
    print(ports)  # shows available ports

    # establish the connection with the obd in asynchronous mode, allowing constant reading of values
    connection = obd.Async(ports[0], baudrate=38400, protocol="3", fast=quick, timeout=30)
    while len(
            connection.supported_commands) < 10:  # tris to connect until 10 valid commands are found
        try:
            connection.stop()
            time.sleep(5)  # wait 5 seconds to allow a proper connection
            connection = obd.Async(ports[0], 38400, "3", fast=quick, timeout=30)

        except Exception as error:  # check if an error happened
            print("error while trying to connect: ", error)

    print("finished")
    if OBDStatus.CAR_CONNECTED:  # check again if connection was successful
        print("connected")
    return connection


# function used to get the new value of speed, also to control if the vehicle is in movement or not
def new_value1(current_speed):
    global high_speed
    global exit_
    global speed
    speed = current_speed.value.magnitude  # assign value to speed
    print(speed)
    if speed < speed_threshold:
        high_speed = False

    else:
        high_speed = True


# Function used to control the loading bar in sync with the connection function
def time_(second, window, thread):
    progress = 0
    for i in range(int(second * 10)):
        time.sleep(1)  # sleep for a while
        progress += 100 / (second * 10)
        window['-SEC-'].click()

        if not (thread.is_alive()):  # check if the other thread is still running or has finished
            window['-THREAD-'].click()
            break
        print("threading1", progress)

    window['-THREAD-'].click()
    print("finished_2")  # confirmation of finished thread


def main():
    sg.theme('Reddit')
    # ----------- Layout creation ----------
    # If you want to change the logo of the project do it here
    logo = "logo.png"
    height = 350
    wide_1 = 650
    wide_2 = 490
    im_ = cv2.imread(logo)
    im_ = cv2.imencode('.png', cv2.resize(im_, (height, height)))[1].tobytes()

    #loading layout
    layout1 = [[sg.Image(data=im_, pad=(200, 0), size=(height, height), background_color='white', key='-IMAGE-')],
               [sg.ProgressBar(30, orientation='h', pad=(200, 0), size=(150, 20), key='progbar')]]

    # layout left camera
    layout2 = [
        [sg.Image(filename=logo, key='image1', pad=(200, 0), size=(wide_1, height))],
        [sg.Text('Left camera', size=(40, 1), justification='center', font='Helvetica 20')]]

    # layout both cameras
    layout3 = [[sg.Image(filename=logo, key='image2', size=(wide_2, height)),
                sg.Image(filename=logo, key='image3', size=(wide_2, height))],
               [sg.Text('Both cameras', size=(40, 1), justification='center', font='Helvetica 20')]]

    # layout right camera
    layout4 = [
        [sg.Image(filename=logo, key='image4', pad=(200, 0), size=(wide_1, height))],
        [sg.Text('Right camera', size=(40, 1), justification='center', font='Helvetica 20')]]

    # Layout when speed over threshold
    layout_in_movement_ = [
        [sg.Image(filename=logo, background_color='white', key='-IMAGE2-', pad=(200, 0), size=(wide_1, height))],
        [sg.Text('Speed over {} km/h'.format(speed_threshold), size=(40, 1), justification='center',
                 font='Helvetica 20')]]

    # layout buttons
    button_size = 15
    layout5 = [
        [sg.Button('Left', size=(button_size, 1), pad=(2, 2), font='Helvetica 14', visible=True, disabled=True),
         sg.Button('Both', size=(button_size, 1), pad=(2, 2), font='Helvetica 14', visible=True, disabled=True),
         sg.Button('Right', size=(button_size, 1), pad=(2, 2), font='Helvetica 14', visible=True, disabled=True),
         sg.Button(button_text='Activate AI Mode 2', size=(button_size, 1), pad=(2, 2), font='Helvetica 14',
                   visible=True,
                   disabled=True, key='-IA-'),
         sg.Button('Exit', size=(button_size, 1), pad=(50, 2), font='Helvetica 14', visible=True)]]

    # main layout
    layout = [[sg.Text('ATTENTION! Watch the surroundings for safety', justification="c", font="Helvetica 30",
                       pad=(230, 0), size=(40, 1), key='text_superior')],
              [sg.Column(layout1, justification="t", element_justification='center', key='-COL1-'),
               sg.Column(layout2, justification="t", element_justification='center', visible=False, key='-COL2-'),
               sg.Column(layout3, justification="t", element_justification='center', visible=False, key='-COL3-'),
               sg.Column(layout4, justification="t", element_justification='center', visible=False, key='-COL4-'),
               sg.Column(layout_in_movement_, justification="t", element_justification='center', visible=False,
                         key='-COL5-')],
              [sg.Button("-SEC-", visible=False), sg.Button('-THREAD-', visible=False)],
              [sg.Column(layout5, justification="r", element_justification='center', visible=True, key='-COL6-')]]

    # defines the window with proper dimensions
    window = sg.Window('Argos Cam', layout, resizable=False, size=(1024, 550)).Finalize()

    timeout = thread = None

    accelerate_progress_bar = False
    timeout = None
    t = 50  # max time of initialization
    c = "a"

    # thread used for the loading screen
    thread = threading.Thread(target=lambda q, arg1: q.put(connect(arg1)), args=(que, c), daemon=True)
    thread1 = threading.Thread(target=time_, args=(t, window, thread), daemon=True)
    thread.start()
    thread1.start()

    # element used to continue updating the progress bar after thread ends
    progress_time = 0

    # load screen
    while True:  # Event Loop
        event, values = window.read(timeout=10)
        # if time ends, exit or cancel buttons clicked loop ends
        if event in (None, 'Exit', 'Cancel') or progress_time > 100:
            break

        if event == '-SEC-':  # internal click to update progress bar
            # when the thread ends the progress bar goes faster
            if accelerate_progress_bar:
                progress_time = progress_time + 1
                window['progbar'].update_bar(time_, 100)
                time.sleep(.1)
                window['-SEC-'].click()
            else:
                progress_time = progress_time + 1
            window['progbar'].update_bar(time_, 100)

        # event called when thread ends, saves the connection element
        if event == '-THREAD-':
            # stops both threads
            thread.join(timeout=0)
            connection = que.get()  # saves connection element
            thread1.join(timeout=0)
            print('Thread finished', thread.is_alive(), thread1.is_alive())
            accelerate_progress_bar = True
            window['-SEC-'].click()

    # Sizes of the images used in the layout
    dispW = 640
    dispH = 480
    height_ = 350
    wide_1_ = 650
    wide_2_ = 490
    print("activate gpio")
    # GPIO.cleanup()
    Jetson = GPIO
    Jetson.setmode(GPIO.BCM)
    pins = [18, 4, 7, 27, 10]  # MODIFY ACCORDING TO YOUR PINS
    Jetson.setup(pins, GPIO.OUT, initial=GPIO.LOW)

    # Neural network can be changed here
    network_name = "ssd-mobilenet-v2"
    net = inference.detectNet(network_name, threshold=0.35)
    camera1 = vStream(net, dispW, dispH, Jetson, 4, 18, 27)
    camera1.open(gstreamer_pipeline(flip_method=2))
    camera1.start()
    camera2 = vStream(net, dispW, dispH, Jetson, 10, 7, 27)
    camera2.open(gstreamer_pipeline(sensor_id=1, flip_method=2))
    camera2.start()

    # start reading values from the car
    connection.watch(obd.commands.SPEED, callback=new_value1)
    connection.start()

    window[f'-COL1-'].update(visible=False)
    layout_visible = 3
    window[f'-COL{layout_visible}-'].update(visible=True)

    # Enables the buttons to control active camera
    window['Left'].update(disabled=False)
    window['Both'].update(disabled=False)
    window['Right'].update(disabled=False)
    window['-IA-'].update(disabled=False)

    # Camera size
    dim_1 = (wide_1_, height_)
    dim_2 = (wide_2_, height_)
    layout_in_movement = True
    intelligent = 1  # 0 deactivate, 1 demo, 2 real

    # main loop
    while True:
        event, values = window.read(timeout=20)

        # if exit button, window closed or keyboard key q pressed program ends
        if event == 'Exit' or event == sg.WIN_CLOSED or cv2.waitKey(1) == ord('q'):  #
            break

        elif event == 'Left':  # if left button pressed, this will be the only camera used and visible
            window[f'-COL{layout_visible}-'].update(visible=False)
            layout_visible = 2
            window[f'-COL{layout_visible}-'].update(visible=True)

        elif event == 'Both':   # Both cameras will be used and shown
            window[f'-COL{layout_visible}-'].update(visible=False)
            layout_visible = 3
            window[f'-COL{layout_visible}-'].update(visible=True)

        elif event == 'Right':  # if left button pressed, this will be the only camera used and visible
            window[f'-COL{layout_visible}-'].update(visible=False)
            layout_visible = 4
            window[f'-COL{layout_visible}-'].update(visible=True)

        elif event == '-IA-':  # By clicking this button the IA method is selected
            if intelligent == 0:  # IA deactivated
                window['-IA-'].update('Activate AI Mode 2')
                intelligent = 1

            elif intelligent == 1:  # IA Method 1
                window['-IA-'].update('Deactivate IA')
                intelligent = 2

            else:  # IA Method 2
                window['-IA-'].update('Activate DEMO Mode')
                intelligent = 0

        if high_speed:
            # modify the layout according to vehicle speed
            # this is done automatically using values acquired using obd reader
            window[f'-COL{layout_visible}-'].update(visible=False)
            window['-COL5-'].update(visible=True)
            layout_in_movement = True

        else:  # cameras start working
            window['-COL5-'].update(visible=False)
            window[f'-COL{layout_visible}-'].update(visible=True)
            layout_in_movement = False

        if not layout_in_movement:  # if car moving at speed lower than speed threshold
            # according to visible layout and AI mode the proper camera algorithms are used
            if layout_visible == 2:
                if intelligent == 2:
                    recognition, frame = camera1.recognition_with_bg()

                elif intelligent == 1:
                    recognition, frame = camera1.recognition_without_bg()
                else:
                    frame = camera1.getFrame()
                    
                #codify image to be used in PysimpleGUI
                imgbytes = cv2.imencode('.png', cv2.resize(frame, dim_1))[1].tobytes()
                window['image1'].update(data=imgbytes)

            elif layout_visible == 4:
                if intelligent == 2:
                    recognition1, frame1 = camera2.recognition_with_bg()

                elif intelligent == 1:
                    recognition1, frame1 = camera2.recognition_without_bg()

                else:
                    frame1 = camera2.getFrame()
                imgbytes1 = cv2.imencode('.png', cv2.resize(frame1, dim_1))[1].tobytes()  # ditto
                window['image4'].update(data=imgbytes1)

            else:
                if intelligent == 2:
                    recognition, frame = camera1.recognition_with_bg()
                    recognition1, frame1 = camera2.recognition_with_bg()

                elif intelligent == 1:
                    recognition, frame = camera1.recognition_without_bg()
                    recognition1, frame1 = camera2.recognition_without_bg()

                else:
                    frame = camera1.getFrame()
                    frame1 = camera2.getFrame()

                imgbytes = cv2.imencode('.png', cv2.resize(frame, dim_2))[1].tobytes()
                imgbytes1 = cv2.imencode('.png', cv2.resize(frame1, dim_2))[1].tobytes()
                window['image2'].update(data=imgbytes)
                window['image3'].update(data=imgbytes1)

    # clean up, and stop threads
    window.close()
    camera1.stop()
    connection.close()
    camera1.capture.release()
    camera2.stop()
    camera2.capture.release()
    GPIO.cleanup()


# main function
if __name__ == '__main__':
    main()

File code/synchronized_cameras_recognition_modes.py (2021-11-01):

# Part of this code is based on Jetson hacks code to control the cameras using threads
# MIT License
# Copyright (c) 2019,2020 JetsonHacks
# See license
# A very simple code snippet
# Using two  CSI cameras (such as the Raspberry Pi Version 2) connected to a
# NVIDIA Jetson Nano Developer Kit (Rev B01) using OpenCV
# Drivers for the camera and OpenCV are included in the base image in JetPack 4.3+

# This script will open a window and place the camera stream from each camera in a window
# arranged horizontally.
# The camera streams are each read in their own thread, as when done sequentially there
# is a noticeable lag
# For better performance, the next step would be to experiment with having the window display
# in a separate thread


# Import needed libraries
import threading
import time
import RPi.GPIO as GPIO
import cv2
import cv2 as cv
import jetson.inference as inference
import jetson.utils as utils
import numpy as np


# class creation to control cameras
class vStream:
    # class initialization with parameters. (Network used, pins used for this camera, frame size)
    def __init__(self, network, width, height, board, pin_led_person, pin_led_car, pin_buzzer):

        ##############################
        # GPIO#
        # parameters used to control GPIO
        self.board = board
        self.pin_led_person = pin_led_person
        self.pin_led_car = pin_led_car
        self.pin_buzzer = pin_buzzer

        # initial state of GPIO pins
        self.board.setup(self.pin_led_car, self.board.OUT, initial=self.board.LOW)
        self.board.setup(self.pin_led_person, self.board.OUT, initial=self.board.LOW)
        self.board.setup(self.pin_buzzer, self.board.OUT, initial=self.board.LOW)
        self.frames_safety_margin = 5  # Safety margin to avoid constant change of state of LEDs or buzzer
        self.buzzer_sound_time = 2 # Number of frames that controls the time the buzzer is producing a noise

        ##############################
        # Camera parameters #
        # frame size definition
        self.width = width
        self.height = height
        self.capture = None
        # Initialize capture parameter

        # Last frame grabbed variable, to store it
        self.frame = None
        self.frame2 = None
        self.grabbed = False
        self.running = True

        ##############################
        # Object recognition#
        self.net = network

        # CHANGE TO REDUCE CONFIDENCE OF OBJECT RECOGNIZED AS AN VALID OBJECT
        self.thr = 0.5  # threshold, 0.5 default value 

        # Names of recognized objects and groups
        self.classes = ['background', 'truck', 'bicycle', 'bus', 'car', 'motorbike', 'person']
        self.classNames = ['person']
        self.classVehicle = ['bicycle', 'truck', 'bus', 'car', 'motorbike']

        # Parameters to control state of GPIO using object recognition
        self.led_person_On = False
        self.led_vehicle_On = False
        self.detected_person = False
        self.detected_vehicle = False

        # Used in combination with variable frames_safety_margin, to control GPIO state
        self.counter_detected_person = 0  # counts the time a person is detected
        self.counter_not_detected_person = 0
        self.counter_detected_vehicle = 0  # counts the time a vehicle is detected
        self.counter_not_detected_vehicle = 0

        ##############################
        # Background subtraction #
        self.box_increase = 15  # increase of bounding box size to ensure moving object is properly recognized later
        self.color = (255, 255, 255)

        # background subtraction algorithm definition and parameters adjustments
        self.fgbg = cv2.createBackgroundSubtractorKNN()
        self.fgbg.setHistory(100)
        self.fgbg.setNSamples(10)
        self.fgbg.setkNNSamples(3)

        # shape and size of kernels used in the project
        self.kernel = cv2.getStructuringElement(cv2.MORPH_CROSS, (5, 5))
        self.kernel1 = cv2.getStructuringElement(cv2.MORPH_ELLIPSE, (7, 7))

        ##############################
        # Thread #
        # parameters to control the thread of the camera
        self.read_thread = None
        self.read_lock = threading.Lock()
        self.running = False

    # Camera initialization
    def open(self, gstreamer_pipeline_string):
        try:
            # The video controller is GStreamer
            self.capture = cv2.VideoCapture(gstreamer_pipeline_string, cv2.CAP_GSTREAMER)
            self.grabbed, self.frame = self.capture.read()

        except RuntimeError:  # Warns of error found
            self.capture = None
            print("Impossible to open camera")
            print("Pipeline: " + gstreamer_pipeline_string)
            return

    # Function to start thread and call function to start capturing frames
    def start(self):
        if self.running:
            print("Already capturing frames")
            return None

        if self.capture is not None:
            self.running = True
            self.read_thread = threading.Thread(target=self.updateCamera)
            self.read_thread.daemon = True
            self.read_thread.start()
        return self

    # Function used to stop the thread
    def stop(self):
        self.running = False
        self.read_thread.join()

    # Function to capture new frames, this function is called by the thread
    def updateCamera(self):
        while self.running:
            # try grabbing new frames
            try:
                grabbed, frame = self.capture.read()
                with self.read_lock:
                    self.grabbed = grabbed
                    self.frame = frame
                    try:
                        # change the frame capture size to neural network input size
                        self.frame2 = cv2.resize(self.frame, (300, 300))

                    except Exception as err:  # check for errors
                        print("camera capture failed", err)

            except RuntimeError:
                print("Impossible to read new frame")

    # Returns the captured frame, without processing and sets the GPIO to low
    def getFrame(self):
        print("frame")
        self.board.output(self.pin_led_car, self.board.LOW)
        self.board.output(self.pin_led_person, self.board.LOW)
        self.board.output(self.pin_buzzer, self.board.LOW)
        return self.frame2

    # Function used to apply the background subtraction to the captured frame
    def Background_subtraction(self):
        try:
            self.blur = cv2.GaussianBlur(self.frame2, (15, 15), 0)  # Blurs frame
            self.fgmask = self.fgbg.apply(self.blur)  # Apply background subtraction
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
